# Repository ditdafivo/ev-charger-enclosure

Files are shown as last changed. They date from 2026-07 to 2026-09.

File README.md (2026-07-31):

# EV charger enclosure

This repository generates an OpenSCAD model, bill of materials, cut list, and
shopping list for a configurable outdoor EV charger enclosure.

## Generate and publish

Install [uv](https://docs.astral.sh/uv/), then run:

```bash
uv run build.py
```

Outputs are written beneath `output/`. By default, the generated model is also
committed to the repository's generated `pages-source` branch and pushed to
GitHub. That push starts the Pages workflow, which rebuilds the browser-based
OpenSCAD Playground at:

<https://ditdafivo.github.io/ev-charger-enclosure/>

Publishing uses the authenticated `origin` Git remote. A network or GitHub
failure produces a warning without discarding local output. To generate files
without publishing, use:

```bash
uv run build.py --no-deploy
```

Automatic publishing is also skipped unless the working tree is clean and the
current commit exactly matches its freshly fetched upstream branch. This keeps
generated Pages deployments from getting ahead of the source code on GitHub.

The `--width`, `--depth`, and `--height` options customize the enclosure. Run
`uv run build.py --help` for their descriptions.

## First deployment

GitHub Pages must use GitHub Actions as its publishing source. If the first
deployment reports that Pages is not enabled, open **Settings → Pages**, choose
**GitHub Actions** under **Build and deployment → Source**, and rerun
`uv run build.py`.

The build also writes `output/gusset_plate_6x6.dxf`, an inch-unit laser-cut
file for the custom G90 top-bracing gusset. To regenerate the committed
fabrication copy directly, run:

```bash
uv run python tools/generate_gusset_dxf.py
```

Printable ASA tambour tracks, removable keyed joint collars, clearance coupons,
end stops, loading sections, and the pull handle are generated as STEP and STL
files beneath `output/tambour/`. Generate the complete set, or one named part,
with:

```bash
uv run python tools/generate_tambour_parts.py
uv run python tools/generate_tambour_parts.py --part clearance_coupon_0.5mm
```

The geometry uses millimetres and targets a 350 mm printer bed with a 0.6 mm
nozzle. Print and condition the clearance coupons before committing to the
production tracks; the default 0.5 mm running clearance is only a starting
point. The generated CSV and JSON manifests give print quantities and finished
bounding dimensions. Print two common dovetail-collar shoes for every track
joint, plus two pull handles. `joint_fit_preview.step` shows two test tracks,
the expansion gap, and both collars in their installed positions.

The workflow builds directly from the pinned public OpenSCAD Playground
submodule. No NAS, container runtime, deployment key, personal access token, or
committed WASM output is required.

## Licensing

The original enclosure code, documentation, and owner-created 3D assets are
available under the [MIT license](LICENSE). The customized and compiled
OpenSCAD Playground remains GPL-covered. See
[THIRD_PARTY_NOTICES.md](THIRD_PARTY_NOTICES.md) for the exact boundary and
third-party licensing information.

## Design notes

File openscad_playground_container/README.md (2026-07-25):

# OpenSCAD Playground Pages build

This directory contains the pinned OpenSCAD Playground source, the GPL-covered
customization patches, and the static GitHub Pages build helper.

Initialize the submodule and generate a local-only enclosure model:

```bash
git submodule update --init
uv run build.py --no-deploy
```

Prepare the model path expected by the Playground, then build with:

```bash
sed 's#../assets/components/ev_charger_plug/ev_charger_plug\.stl#ev_charger_plug.stl#' \
  output/model.scad > /tmp/model.scad
./openscad_playground_container/scripts/build-pages.sh \
  /tmp/model.scad openscad_playground_container/dist local
```

Normal publication does not require this manual step. `uv run build.py` pushes
the prepared model to `pages-source`, and `.github/workflows/deploy-pages.yml`
runs the helper and publishes its output.

The build copies the upstream license bundle and an exact corresponding-source
revision notice into the deployed site. See the repository's
`THIRD_PARTY_NOTICES.md` for licensing details.

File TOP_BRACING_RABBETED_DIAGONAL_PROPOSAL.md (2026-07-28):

# Custom-gusset top-diagonal detail

## Status and purpose

This document records the implemented replacement for the catalog-plate joint
in the previous top-bracing commit. The structural screening load and member
checks remain in [`TOP_BRACING.md`](TOP_BRACING.md).

## Implemented framing

- `brace_fl_bl` and `brace_fr_br` remain top-flush 4x4 side members from
  `z = 43.50` through `z = 47.00`.
- The front and rear perimeter members remain top-flush 2x4s.
- `post_bl` and `post_fr` are 3/4 inch shorter than the other posts and stop at
  `z = 46.25`. They are not rabbeted.
- The diagonal is ripped from nominal 1x6 stock to a calculated 4.907-inch
  default finished width and occupies `z = 46.25` through `z = 47.00`. Its
  35.133-inch rectangular blank follows the post-center line at 37.44 degrees.
  Both ends are jigsawed to the modeled six-sided footprint, fully covering
  both post tops without crossing their exterior XY faces.
- The diagonal's footprint is routed 3/4 inch into the four intersected side
  braces. There are no routed post seats.

The angled board fills both shortened posts' complete top footprints. Its
minimum width is recalculated from post spacing as the square-post projection
normal to the center-to-center brace axis.

## Custom gusset

Each involved corner receives one flat 6-by-6-inch laser-cut plate. The plate
is positioned against the corner's two exterior post faces and extends inward,
covering the post, both adjoining side braces, and the diagonal.

Fabrication specification:

| Property | Value |
|---|---:|
| Material | G90 galvanized steel |
| Thickness | 0.074 inch |
| Overall outline | 6.000 by 6.000 inches |
| Hole pattern | 4 by 4 square grid |
| Hole center coordinates on each axis | 0.750, 2.250, 3.750, 5.250 inches |
| Hole diameter | 13/64 inch (0.203125 inch) |
| Quantity | 2 identical plates |

The DXF uses inches and contains one closed outline plus sixteen circle
entities on the `CUT` layer. Generate it with:

```text
uv run python tools/generate_gusset_dxf.py
```

The committed result is `fabrication/gusset_plate_6x6.dxf`; a normal model
build also writes `output/gusset_plate_6x6.dxf`.

## Fasteners

Model sixteen #9 pan-head screws per plate, thirty-two total. The OpenSCAD
geometry represents only each pan head above the plate. Neither the model,
DXF, BOM, nor instructions model or specify screw length.

The uniform grid is positioned so its centers lie over the post, side braces,
or diagonal in the default geometry. Final screw type, length, coating,
penetration, edge distances, and group capacity require an approved structural
connection design. The custom plate must not be assigned a catalog connector's
published capacity.

## Roof interface

The plate plus modeled screw head projects 0.184 inch above `z = 47.00`.
The 1/4-inch ripped pressure-treated shims cover the exposed perimeter framing
and both non-gusseted corner posts, stop at the gusset envelopes, and retain the
roof support plane at `z = 47.25`. The decking spans the short interruptions and
finishes at `z = 48.25`.

## Acceptance checks

Before removing temporary bracing, verify:

- the shortened posts terminate at the diagonal underside and have no routed
  top seats;
- no diagonal geometry extends past the exterior XY faces of either involved
  post;
- all four side-brace rabbets are flat, full depth, and free of splits;
- both gussets sit flat across the modeled intersection;
- every screw location has solid wood below it;
- the selected fasteners and custom plate have an approved capacity for the
  798-pound ASD diagonal demand documented in `TOP_BRACING.md`;
- roof shims stop clear of the plates and heads while preserving drainage; and
- tambour, wiring, siding, and service clearances remain unobstructed.

## Decision log

| Date | Decision | Result |
|---|---|---|
| 2026-07-27 | Fully cover both shortened post tops with the diagonal. | The brace now follows the post-center line, is ripped from 1x6 stock to the calculated minimum width, and has jigsaw-profiled ends. |
| 2026-07-27 | Remove the former diagonal extensions beyond the posts. | Superseded by the full-post, jigsaw-profiled detail above. |
| 2026-07-27 | Shorten the involved posts instead of rabbeting them. | `post_bl` and `post_fr` stop 3/4 inch below the frame top. |
| 2026-07-27 | Retain rabbets only at intersected side braces. | Four routed seats remain. |
| 2026-07-27 | Replace HTP37Z hardware with custom gussets. | Two identical 6-by-6-by-0.074-inch G90 plates with sixteen-hole grids are modeled. |
| 2026-07-27 | Leave #9 pan-head screw length open. | Heads and quantities are modeled; length is absent from all specifications. |

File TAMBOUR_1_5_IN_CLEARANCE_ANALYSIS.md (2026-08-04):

# Tambour 1.5-Inch Slat Clearance Analysis

## Conclusion

The modeled tambour clears the fixed framing, siding, street-light backers,
revised charger-feed conduit, and removable plywood ceiling throughout a dense
sweep of the complete track. The check uses the actual asymmetric envelope:
7/8 inch outward from the track centerline for the slat and handle, and
5/16 inch inward for the slat, webbing, reinforcement, and fastener heads. The
1 3/16-inch actual stack remains inside the 1 1/2-inch maximum envelope.

The production channel clearance, printed-track fasteners, slat-end clearance,
joint clips, loading section, and exact inward fastener stack remain
prototype-controlled. The rendered
charger cord is illustrative
and is not treated as a hard clearance envelope; the plywood ceiling guards the
overhead curtain from hands and the cord.

## Resolved geometry

| Region or object | Result |
| --- | ---: |
| Perimeter top braces | 0.25-inch clearance |
| Shallow top diagonal | Approximately 1-inch clearance |
| Lowered `rail_ft` and front bend | At least 0.25-inch modeled clearance |
| Front street-light backers | 0.325-inch planar clearance |
| Charger-riser feed | Clears below or behind the front curtain |
| Plywood ceiling | 0.25 inch below the horizontal curtain envelope |
| Rear trim and lateral slat ends | Prototype-controlled guide detail |

### Front guide and street-light backers

The slat and guide share the groove centerline at `y = 5.0`. The minimum safe
datum from the fixed street-light backers is `y = 4.925`; it is rounded
rearward to the next 1/8 inch for construction. The outward handle envelope
therefore reaches forward to `y = 4.125`, while the backers end at `y = 3.80`:

```text
4.125 - 3.80 = 0.325 inch
```

The left and right vertical support rails move with the guide and occupy
`y = 4.25` to `y = 5.75`. The 3/4-inch plywood bend backers continue rearward
to `y = 7.25` and occupy `z = 42.375` to `z = 43.5`, above `rail_lt` and
`rail_rt`, so the complete printed flange remains supported without overlapping
the receiver rails.

### Structural front header

`rail_ft` remains a 2x4 but moved down to `z = 40.875` through `z = 42.375`.
The front center rail bears against its underside. The header spans directly
between `rail_lt` and `rail_rt`, which provide its full-depth end attachment
faces; the former vertical header-support blocks are not used.

The regression follows the resolved piecewise track and checks both the full
7/8-inch outward handle envelope and the full 5/16-inch inward slat/hardware
envelope over the header's Y interval and through both bends. Separate dense
samples of the complete printed-track cross section prove backing support and
absence of lumber penetration through the 2 5/8-inch-radius front bend.

This is a geometry result, not a structural rating. The header, blocks, center
rail, fasteners, and connections must be selected for the charger dead load
and repeated lateral and torsional loading from wrapping the cord and handling
the plug.

### Charger-feed conduit

The charger-riser arrangement aligns the 1 1/4-inch ground riser and T body
with the charger's conduit-port X coordinate. Its complete horizontal branch
runs 1/4 inch above `rail_fb` to the rear of the junction box, while the
reduced 1-inch feed rises directly from the T body to the charger. Both feeds
remain below or behind the front curtain envelope.

The #6 charger group bypasses the junction box through the T body. The box's
remaining #12 groups require 18 cubic inches against its modeled 49-cubic-inch
marking, leaving 31 cubic inches.

### Removable plywood ceiling

The modeled exterior-plywood panel occupies:

```text
x = 3.5 to 24.0 inches
y = 9.6875 to 17.625 inches
z = 43.25 to 43.50 inches
```

Its top is 9/16 inch below the inward horizontal curtain envelope at
`44.375 - 0.3125 = 44.0625` inches.
Its rear edge is inset 3/4 inch from the rear bend tangency; its front edge
aligns with the positive-Y face of `rail_ft`. Mount it on independent removable
retainers so track inspection, cleaning, and curtain removal remain possible.

## Rear trim and slat ends

“Rear trim and slat ends” refers to the left and right ends of each slat where
the curtain passes through the rear opening, not the trailing end of the
curtain. The simplified model draws each slat to both track centerlines, while
the rear opening angles reach those same lateral boundaries. A production
slat instead terminates with running clearance inside the printed side-opening
channel, with the trim concealing the interface.

Because the accepted printed clearance, end engagement, and installed track
spacing remain prototype-controlled, this interface must be approved on the
full-width test frame.

## Acceptance requirements

1. Build the guide paths from one full-size template using the modeled
   front `y = 5.0`, top `z = 44.375`, rear `y = 21.0`, and 2 5/8-inch-radius
   track datums.
2. Verify the header load path and connections for the charger and holster's
   dead and dynamic loads.
3. Prototype the printed channel, clearance coupons, slat ends, pulls,
   fasteners, loading section,
   and removable ceiling retainers.
4. Cycle the curtain through full travel before and after installing the
   ceiling, conduit, fixed cables, siding, and trim.
5. Record the production dimensions and revise the model if the approved
   prototype differs from the modeled maximum envelope.

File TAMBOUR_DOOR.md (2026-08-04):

# Custom Tambour Door Prototype and Build Guide

This guide defines how to develop, prove, fabricate, install, and maintain the
custom tambour door shown in the enclosure model. It supplements
[`BUILD_STEPS.md`](BUILD_STEPS.md); it is not a claim that the current modeled
slat and track dimensions are a proven shop drawing.

The door is intended to be an attractive visual barrier that is easy to open,
close, clean, and service. It is not a security barrier or a weather seal. Do
not add locks, gaskets, springs, or counterweights without revisiting the path,
clearances, operating force, and maintenance requirements.

## Modeled starting geometry

Use these values to lay out the first full-size prototype. Values marked
"prototype-controlled" may change before production and must be recorded in
the build record at the end of this guide.

| Feature | Modeled value | Status |
| --- | ---: | --- |
| Distance between left and right track centerlines | 20 1/2 in | Verify against the built frame |
| Rear lower track endpoint | `y = 21`, `z = 3` in | Fixed enclosure interface |
| Front lower track endpoint | `y = 5`, `z = 16` in | Fixed enclosure interface |
| Top track centerline | `z = 44 3/8` in | Fixed enclosure interface |
| Rear straight run | 38 3/4 in | Derived from installed datums |
| Top straight run | 10 3/4 in | Derived from installed datums |
| Front straight run | 25 3/4 in | Derived from installed datums |
| Track offset into slat | 0 in; path is groove center | Fixed enclosure interface |
| Bend centerline radius | 2 5/8 in | Prototype-controlled |
| Curtain length | 44 in | Prototype-controlled |
| Slat pitch | 25/32 in | Prototype-controlled |
| Slat travel-direction height | 3/4 in | Prototype-controlled |
| Wooden slat face depth | 1/2 in | Prototype-controlled |
| Complete swept depth envelope | 1 1/2 in | Fixed clearance limit |
| Rendered track diameter | 1/2 in | Visualization only |
| Removable ceiling panel | 20 1/2 by 7 15/16 by 1/4 in | Fixed enclosure interface |

The model places 56 slats on the 44-inch curtain. The 1/32-inch difference
between the 3/4-inch slat height and 25/32-inch attachment pitch is a setup
allowance, not a promise of a permanently visible gap. The lower stop supports
the closed curtain, adjacent slats may settle together, and the webbing can bow
locally. The detailed model draws the channel and its mounting flange; printable
track solids and test coupons are generated separately with build123d.

The track datum and wooden slat center now share the running-groove centerline.
In the X direction, that datum is also the lumber mounting face: the printed
flange and channel project from it into the door opening rather than into the
supporting lumber.
The actual 1/2-inch slat is rendered at `z = 44.375` on the top run. Clearance
checks use an asymmetric swept envelope: 7/8 inch outward from the groove
centerline for the slat plus 5/8-inch handle, and 5/16 inch inward for the slat
plus no more than 1/16 inch of webbing, reinforcement, and fastener-head
projection. The resulting 1 3/16-inch stack remains within the fixed
1 1/2-inch maximum. The outward envelope retains 1/4 inch below the braces:
`44.375 + 0.875 = 45.25` inches. No handle, screw head, webbing, reinforcement,
or track fixing may extend beyond its applicable side of this approved
envelope.

## Provisional construction

Use the following construction family for the prototypes:

- Dry, straight pressure-treated stock surfaced to 1/2 inch for the slats.
  Reject twisted, cupped, checked, severely incised, or irregular stock. Use a
  planer, purchased surfaced stock, or outsourced milling rather than resawing
  a wide board on edge with only a table saw. Field-treat and seal cut faces.
- At least three exterior-rated polyester webbing strips on the concealed face,
  mechanically fastened to every slat without pre-tension. Keep fasteners clear
  of the captured ends and handle screws.
- ASA track segments with integral mounting flanges as the replaceable running
  surface. Print the clearance coupons before production parts; a separate
  UHMW liner is not part of the initial design.
- Corrosion-resistant fasteners outside the running surface. Fix each track
  segment at its center and use slotted outer holes so it can expand without
  buckling.
- Replaceable end stops and paired removable loading sections at the lower rear
  ends of the tracks. The curtain must remain removable after siding, trim, and
  electrical equipment are installed.

Make both guide paths from the same full-size master template. Mark every
track segment, keyed collar, spacer, loading section, and end stop
left/right and front/rear so that matched pieces return to their proven
positions. Keep the running surfaces
smooth and free of exposed screw heads, abrupt joints, plastic strings,
and pockets that retain grit or water. Provide cleanout and drainage at both
low endpoints.

Commercial tambour instructions emphasize consistent, aligned tracks and
keeping debris out of the slats. Printed ASA also requires expansion gaps and
independently aligned segments rather than a long rigid run. See the
[Tambour Doors installation guidance](https://tambourdoors.eu/installation-guides/),
[Tambortech installation instructions](https://www.tambortech.com.au/fileadmin/user_upload/downloads/2013_Tambour_Door_Install_Sheet.pdf),
and the printable-part instructions below.

## Printable ASA parts

Run `uv run python tools/generate_tambour_parts.py` to write the complete STEP,
STL, and quantity manifests beneath `output/tambour/`. Use `--part NAME` while
developing a coupon or replacement. Do not scale meshes in the slicer; change
the Python configuration and regenerate them so track and collar clearances stay
coordinated.

The baseline assumes a 0.6 mm nozzle, 0.3 mm or finer layers, at least four
perimeters, and an enclosed ASA-capable printer. Put each track's mounting
flange on the build plate; both handed exports are already oriented this way.
Use enough top and bottom layers and infill to make screw counterbores and the
handle ribs solid in practice. Follow the filament manufacturer's temperature,
drying, ventilation, and fume-control instructions. Do not anneal production
parts unless identically treated coupons demonstrate that dimensional change
does not consume the accepted running clearance.

The fixed straight runs are divided into equal segments below 300 mm. The rear
loading section replaces the lowest 100 mm of fixed track; it is not added to
the path length. Keep the configured 0.6 mm expansion seam between track ends.
At every joint, slide one external dovetail-collar shoe down each channel wall,
then retain each shoe with a recessed M3 stainless screw in its heat-set insert.
The shoes index both channel walls while leaving the running channel empty and
allowing limited longitudinal thermal movement. Remove both screws and lift the
shoes outward before lifting an individual segment. The collars align the
tracks but do not replace the segment mounting screws. Print the two joint-test
tracks first and inspect `joint_fit_preview.step` for the installed orientation.
Keep the open drain notch in each lower stop unobstructed.

## Pull slats

Make two special pull slats as part of the curtain:

1. The lowest slat is the normal opening pull. When the door is open, this slat
   travels onto the upper run and also serves as the closing pull.
2. Place a second pull approximately 18 inches above the lower curtain edge.
   At the modeled 25/32-inch pitch this is nominally the twenty-fourth slat when
   the lowest slat is counted as the first. Set its final position from the
   actual production pitch, not merely the nominal slat count.

Rear elevation, door closed (not to scale):

```text
                  top track centerline z = 44.375
       left track  |==========================|  right track
                   |                          |
                   |  upper printed lift ledge|  about 18 in above lower edge
                   |  <-------------------->  |
                   |                          |
                   |  lowest printed lift ledge| normal opening pull
                   |  <-------------------->  |
                   +--------------------------+  lower edge about z = 3
```

Side path and handle orientation (not to scale):

```text
 rear opening                                      enclosure front
 y = 21                                                     y = 5
    |        top brace underside z = 45.5                    |
    |        ----------------------------------               |
    |        1/4-in minimum clearance                         |
    |      / printed ledge rotates onto top run \              |
    |     /======================================\ z = 44.375 |
    |     |                                      |            |
    |     |                                      |            |
 z = 3 --+                                      +-- z = 16

 The modeled 5/8-in proud handle is included in the 1/4-in clearance.
 The printed ledge must remain inside the approved 1 1/2-in envelope.
```

The model includes a removable 1/4-inch exterior-plywood ceiling from
`y = 9.6875` to `y = 17.625` and `z = 43.25` to `z = 43.5`. Its front edge
aligns with the positive-Y face of `rail_ft`, avoiding an unnecessary forward
overhang. It shields the overhead curtain from hands and the charger cord while
retaining 1/4 inch below the maximum curtain envelope. Support it on independent
removable retainers; do not fasten through a printed track or obstruct track
inspection.

Attach one centered printed ASA lift ledge to each pull slat. The nominal ledge
is 300 mm wide, no more than 5/8 inch proud of the wood face, and secured from
the outward side with multiple short corrosion-resistant wood screws in
recessed counterbores. The screw tips must not penetrate the concealed face;
the modeled handle attachment therefore has no screw head on the inward plane.
It must remain entirely on one slat and permit a centered one-hand grip or a
wide two-hand grip.

The approved pull profile must meet all of these conditions:

- Nothing projects beyond the approved asymmetric swept envelope in any
  direction.
- Webbing, reinforcement, and all heads on the inward face project no more than
  1/16 inch beyond that face. A proposed through-fastener with its head or nut
  on the inward face is a design change and must pass the bend coupon before
  use; it is not the modeled handle fastening method.
- The printed grip and its edges are smooth, rounded, drainable, and free of
  layer separation or sharp support scars.
- Screw pilot holes retain enough wood to keep the 1/2-inch pull slat straight
  under the proof load without penetrating the concealed face.
- The webbing connection at each pull slat is reinforced within the approved
  curtain envelope. Force on the upper pull must not depend only on one screw
  or one webbing strip.
- The grip cannot trap a finger against the next slat or either track while the
  curtain enters a bend.

A bail, folding handle, knob, proud screw, or webbing loop is not acceptable:
every slat-mounted feature travels through both bends and under the top
bracing. Prototype the printed ledge and complete fastener stack before making
the full curtain.

## Prototype sequence

Do not fabricate the final curtain and tracks in one pass.

### 1. Material and pull coupons

Mill several short 1/2- and 3/8-inch-deep slats at the modeled 3/4-inch height.
Ease the moving edges, fasten actual webbing, and mount one printed handle.
Apply the proposed field treatment and finish. Check articulation, screw
holding, drainage, grip comfort, and whether the pull remains straight under
the 15-pound proof load described below. Keep 1/2 inch as the production depth
unless the thinner coupon passes every wind and durability test.

### 2. Full-size path template

Lay out the complete side path at full scale, including both 2 5/8-inch-radius
bends and both lower endpoints. Use a fair curve with tangent transitions; do
not approximate the bend with a sharp miter. Make a rigid master template and
use it for both mirrored track assemblies.

### 3. Short-curtain track test

Print the 0.3, 0.5, and 0.7 mm-per-face clearance coupons, then one complete
bend and its tangent stubs. Run a short webbing-linked group of ordinary and
pull slats through it. Select the tightest conditioned coupon that runs freely,
then adjust only slat edge easing and setup gap until the sample moves without
pinching, chatter, or visible skew. Generate both track hands with that
accepted clearance.

### 4. Full-width test frame

Build a rigid test frame at the measured production track spacing. Use fixed
spacers or an alignment gauge at the rear vertical, both bends, top run, and
front vertical. Install the removable loading sections and end stops exactly
as they will be installed in the enclosure.

### 5. Full-curtain test

Fabricate the 44-inch curtain using the two pull slats. Load it through the
service sections, fit the stops, and perform the acceptance tests below. Test
the bottom pull from the center and with hands spread toward both tracks. Test
the upper pull the same way.

If the completed door exceeds the operating-force limit, first reduce the slat
mass and repeat the short-curtain and full-curtain tests. Adjust the model after
the production profile is approved. Do not mask an excessively heavy curtain
with extra track friction, and do not add a spring or counterweight as part of
this design.

## Enclosure installation

Install the approved tracks only after both vertical supports, both 3/4-inch
plywood bend backers, and the top side 4x4s are fixed. Install and verify the
tracks before loading the door, and complete both operations before electrical
backing, conduit, siding, or trim restricts access.

1. Measure the actual frame and compare it with the prototype test frame.
2. Use the prototype alignment gauges to position both guide paths. Shim the
   mounting flanges as needed; do not pull a crooked segment straight with
   screws.
3. Fix each ASA segment at its center, use its slotted outer holes, preserve
   the accepted joint gaps, and keep every fixing outside the running surface.
4. Load the completed curtain and cycle it fully. Confirm the printed pulls
   clear both bends and all installed framing, including at least 1/4 inch of
   clearance below the already installed top braces throughout their travel.
5. Mark all matched parts, then remove the curtain, loading sections, and end
   stops. Cover the fixed tracks against dust, cuttings, paint, and finish
   during the remaining work.
6. After siding and trim, uncover and clean the tracks. Confirm that no
   fastener or trim movement changed their spacing.
7. Reinstall the curtain, loading sections, and stops, then repeat the full
   acceptance test, including clearance from the already completed conduit
   and fixed cable routes. Install the removable ceiling and repeat the test.

The rendered charger cord is illustrative rather than an accurate operating
envelope. Do not use its modeled path as a hard tambour-clearance datum; the
ceiling panel provides the physical guard beneath the overhead curtain.

The OpenSCAD build-step view shows the completed tambour assembly beginning at
its trial-fit step. It does not attempt to depict the curtain's temporary
removal during the intervening construction work.

## Snow operation

The modeled lower curtain edge is only about 3 inches above nominal grade, so
drifting, shoveled, or plowed snow can cover the lowest pull even though the
door is not intended as a weather barrier. The upper pull provides a reachable
grip; it is not a pry point for breaking a frozen door loose.

After snowfall:

1. Clear snow away from the face of the curtain, both track edges, and the rear
   lower track endpoints.
2. Free any ice bond without levering against a slat or printed track.
3. Use a wide or two-handed grip on the upper printed pull and apply smooth,
   even force until the bottom pull is exposed.
4. Transfer to the bottom pull for normal operation.
5. Stop if the door racks, binds, or requires more than its normal operating
   effort. Clear the obstruction rather than forcing the curtain.

## Acceptance tests

Approve the production design only after it passes all of the following on the
full-width test frame and again in the enclosure:

- Complete at least 100 full open-close cycles without binding, derailment,
  webbing separation, handle damage, or visible track wear.
- Measure no more than 5 pounds peak normal operating force anywhere in the
  travel, using the center and the left and right thirds of both pulls.
- Apply a 15-pound static load to each printed pull for one minute without
  cracking, permanent deformation, screw withdrawal, or webbing separation.
- Apply approximately 4.7 pounds uniformly to a conditioned full-span slat and
  screen the complete closed door and supports for the project's approximately
  260-pound distributed ultimate wind load.
- Confirm that center operation does not rack the curtain and that a deliberate
  modest left/right imbalance does not cause derailment.
- Confirm that the curtain cannot run away, leave either endpoint, or create an
  accessible pinch point during ordinary operation.
- Sweep the complete handle and reinforcement envelope through both bends and
  the top run without contact.
- Remove and reinstall the curtain without removing siding, trim, electrical
  equipment, or a permanent track section.
- Repeat the functional and clearance checks after track installation, after
  siding and trim, and after the final cable routes are installed.

## Production build record

Complete this record before final fabrication and use the approved values to
update the model and generated material outputs in a later change.

| Item | Approved value or product |
| --- | --- |
| Actual installed track spacing | |
| Bend radius | |
| Slat species and moisture condition | |
| Slat pitch, travel width, depth, and end clearance | |
| Ordinary edge profile | |
| Printed pull revision, projection, and screw pattern | |
| Upper pull position from lower curtain edge | |
| Webbing product, strip count, and screw pattern | |
| Field treatment and surface preparation | |
| Finish and maintenance interval | |
| ASA product, clearance coupon, and expansion allowance | |
| Fasteners and slot dimensions | |
| Loading-section and end-stop details | |
| Measured peak operating force | |
| Prototype cycle count and date | |

Until this record is complete, the tambour materials are provisional and are
not included in the generated BOM or shopping list. After approval, follow up
by splitting guide tracks, ordinary slats, and pull slats into distinct modeled
objects and adding their approved materials to the generated BOM and shopping
list.

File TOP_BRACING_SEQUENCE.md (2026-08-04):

# Top-bracing build-sequence evaluation

## Question

Record why the accepted rabbeted top bracing is installed immediately after
the posts rather than after the intermediate framing.

## Conclusion

Install the accepted rabbeted top bracing directly after the posts using the
detail in [`TOP_BRACING.md`](TOP_BRACING.md). Keep temporary external bracing
until the routed seats, custom gusset plates, complete #9 screw grids, and frame
have been inspected.

## Consolidated geometry

The left and right top perimeter members are 4x4s spanning `z = 43.50` to
`47.00`. Their inside faces and undersides replace the former top track rails,
while `rail_lt` and `rail_rt` remain below them as the side receivers for the
lowered front header. The removable ceiling remains at `z = 43.25` to `43.50`,
directly against the 4x4 undersides, while the curtain and guides remain inside
the clear opening.

The full-section diagonal remains at `z = 46.25` to `47.00`. The two involved
posts stop at its underside, and only the four intersected side braces are
routed. Custom 0.074-inch gusset plates and modeled screw heads project 0.184
inch above the frame. The 1/4-inch shims cover the exposed perimeter framing
and both non-gusseted corner posts, stop at the gusset envelopes, and establish
the roof support plane at `z = 47.25`.

## Reasons for moving the bracing after Step 2

### No modeled dependency on intermediate framing

All four perimeter members and the single diagonal connect only to the four
posts. They do not depend geometrically on the lower rails, upper rails,
vertical rails, tambour supports, door, or street-light backing introduced in
Steps 4 through 12.

The reorder is therefore feasible from the model's dependency standpoint.

### Earlier control of frame squareness

Installing the top perimeter and diagonal while the posts are being aligned
would establish the final top rectangle earlier. This reduces the period in
which plan squareness depends entirely on temporary external bracing and makes
it less likely that later installation of the permanent diagonal will disturb
already positioned framing or guide tracks.

The posts should be checked for plumb, spacing, and equal plan diagonals before
the permanent members are fastened. Those measurements should be repeated
after fastening so the bracing does not lock an error into the frame.

### Better tambour alignment and acceptance testing

The former sequence trial-fitted the tambour before installing the permanent
top bracing and checked the curtain against the bracing's modeled envelope.
With the bracing installed earlier, the production tracks and curtain are
aligned and tested against the actual completed framing.

This is preferable because the installed braces, connections, and permitted
construction tolerances—not their idealized model envelopes—control the real
clearance.

### Improved access from the shallow diagonal

The rabbeted, ripped nominal 1x6 diagonal has an underside at `z = 46.25` inches.
The maximum approved tambour envelope reaches `z = 45.25` inches on its top
run, leaving approximately:

```text
46.25 - 45.25 = 1.00 inch
```

This 1-inch minimum clearance beneath the diagonal is substantially greater
than under the former 2x4 diagonals. It makes early installation less likely
to obstruct later tambour work.

The side 4x4s occupy the former side-support footprint rather than crossing the
clear curtain opening. Verify the production tracks, curtain, printed pulls,
fasteners, and ceiling retainers against their actual inside faces.

## Temporary-bracing limitation

Early installation of the top-plane bracing is not by itself a reason to
remove all temporary external bracing. It controls distortion of the top
rectangle, but it does not necessarily prevent all four posts from leaning or
swaying together in a vertical plane.

The build guide should continue to require temporary support until the
installed rails and other permanent framing provide adequate stability in
every direction and the permanent top-brace connections have been approved.

## Structural-connection installation

Route and dry-fit the four side-brace seats before installing hardware. Place
each 6-by-6 gusset against the two exterior faces of its post and fill its
sixteen-hole grid with #9 pan-head screws. The model intentionally leaves screw
length unspecified. Inspect plate seating, wood splitting, screw clearance,
and the post/perimeter load path before removing temporary support.

## Revised sequence

The revised sequence is:

1. Complete the underground conduit risers and restore grade.
2. Install the four posts with temporary external bracing.
3. Install the complete top perimeter and diagonal bracing while checking post
   plumb, spacing, plan diagonals, and the approved connection details.
4. Complete the lower and upper framing through Step 9.
5. Install the plywood bend backers in Step 10, the fixed tracks in Step 11,
   and the tambour door in Step 12.
6. Trial-fit the removable guard in Step 13, then complete the electrical,
   siding, trim, and finish work through Step 27.

The complete sequence contains 27 build steps, so `build_step = 28` represents
the completed model.

## Implemented project updates

The model, tambour prototype guide, build sequence, and build-step assertions
use the resolved geometry and early-bracing sequence. The tambour trial fit is
performed against the installed bracing, and temporary external bracing remains
required until the permanent frame and connections are approved and stable.

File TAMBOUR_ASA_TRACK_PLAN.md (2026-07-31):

# Lightweight ASA Tambour Track and Wooden Curtain

## Summary

Design a modular ASA track and lightweight wooden tambour using 1/2-inch-thick,
3/4-inch-high pressure-treated slats. The slats settle against one another when
closed; mechanical webbing links them, limits separation, and pulls them during
closing but does not hold them apart under gravity.

Retain the existing 1 1/2-inch swept clearance envelope and 2 5/8-inch bend
radius. Prototype 3/8-inch slats as an optional later weight reduction, but use
1/2 inch as the production baseline unless the thinner version passes the same
wind, screw-holding, and durability tests.

## CAD and model changes

- Add build123d as a pinned dependency and generate exact STEP and STL
  fabrication files beneath `output/tambour/`.
- Generate mirrored track sets with straight sections no longer than 300 mm,
  exact tangent bends, side-opening U-channels, integral mounting flanges,
  expansion slots, drainage, removable loading sections and stops, and paired
  external keyed collars that align both channel walls while permitting
  individual segment removal.
- Size printable features for a 0.6 mm nozzle, including nominal 2.4 mm minimum
  walls and reinforced channel/flange transitions.
- Give every track end exterior dovetail pads and retain each paired collar
  with a recessed M3 stainless screw and heat-set insert. Preserve a nominal
  0.6 mm end gap and keep all joint features outside the running channel.
- Provide 0.3, 0.5, and 0.7 mm-per-surface running-clearance coupons. Generate
  production tracks using the tightest clearance that passes the conditioned
  coupon and bend tests.
- Model the actual 1/2-inch slat depth, 3/4-inch travel height, initial
  1/32-inch straight-run gap, 25/32-inch attachment pitch, 44-inch curtain,
  retained 3/8-inch guide-datum offset, and an independent 1 1/2-inch swept
  assembly envelope.
- Generate a replaceable, centered, approximately 300 mm-wide ASA lift ledge
  on each of two pull slats. Limit projection to 5/8 inch and keep every handle
  entirely on one slat and inside the swept envelope.

## Curtain fabrication

- Obtain pressure-treated stock that can be safely surfaced to 1/2 inch using
  a planer, purchased surfaced stock, or outsourced milling. Do not resaw a
  wide board on edge using only the table saw.
- Dry and acclimate stock before final surfacing. Reject warped, checked,
  twisted, or severely incised pieces and record moisture condition.
- Rip the surfaced stock into 3/4-inch-high slats using a repeatable table-saw
  jig. Crosscut from one stop, ease moving edges, and field-treat and seal every
  cut or surfaced face.
- Lay slats face-down against 1/32-inch setup spacers and attach at least three
  exterior-rated polyester webbing strips without stretching them. Fasten the
  webbing mechanically to every slat, outside the track and handle regions.
- Let the lower stop carry the closed curtain vertically. Slat contact carries
  compression; the webbing is not a tensioned spacing belt in this state.

## Structural and wind validation

- Use the existing 44.1 psf ultimate wind-pressure screen. Check each
  20 1/2-by-3/4-inch slat for approximately 4.7 pounds of distributed load and
  the complete door and supports for approximately 260 pounds distributed over
  the door area.
- Test conditioned full-span 1/2- and 3/8-inch coupons with at least 5 pounds
  distributed across one slat. Inspect bending, permanent set, splitting,
  track-edge crushing, and fastener movement.
- Retain 1/2 inch as the production thickness. Adopt 3/8 inch only after it
  passes all structural and operating tests with acceptable margin.
- Treat calculations as screening and prototype requirements rather than a
  stamped structural rating.

## Prototype sequence

1. Print clearance, keyed-collar joint, screw-slot, and handle coupons.
2. Mill short 1/2- and 3/8-inch samples and test finish, swelling, screw holding,
   and edge treatments.
3. Build one complete bend with short straight sections.
4. Assemble a short curtain at 25/32-inch pitch with 1/32-inch setup gaps and
   the actual webbing.
5. Verify settling, bend articulation, edge clearance, and visual closure.
6. Adjust only edge treatment, setup gap, and accepted channel clearance from
   these tests; retain 3/4-inch slat height and 1/2-inch production thickness.
7. Build a rigid full-width test frame using installation gauges.
8. Assemble and test the complete curtain and both pull slats.

## Acceptance criteria

- Complete at least 100 full cycles without binding, derailment, webbing
  separation, joint catching, handle damage, or significant track wear.
- Require no more than 5 pounds peak operating force for centered and
  deliberately off-center pulls.
- Apply a 15-pound handle load for one minute without cracking, screw
  withdrawal, splitting, or permanent deformation.
- Confirm gravity-assisted closure without manually stacking individual slats,
  visually minimal gaps, and no binding after moisture conditioning.
- Pass the distributed slat and complete-door wind tests.
- Keep all actual components inside the 1 1/2-inch swept envelope.
- Permit track-segment, loading-section, stop, handle, and curtain replacement
  without removing siding or permanent electrical equipment.
- Require the keyed joint coupon to cross without catching, withstand a
  10-pound transverse load, and survive 25 removal/reinstallation cycles.
- Repeat operating and clearance tests after final track installation, siding,
  trim, electrical routing, and ceiling installation.

## Assumptions

- The tambour is a visual barrier, not an airtight weather seal or security
  door.
- Shorter 3/4-inch-high slats improve articulation; additional slats restore
  the required curtain length.
- Gravity may reduce straight-run gaps because webbing can bow locally, but
  operation cannot depend on uncontrolled slack.
- Captured slat ends and tracks carry transverse wind load; webbing primarily
  maintains continuity and alignment.
- ASA is a replaceable direct-running guide material without an initial UHMW
  liner.
- Drilling, countersinking, sanding, planing, and jig-making tools may supplement
  the table saw. No router is required.

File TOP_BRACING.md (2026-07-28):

# Top-plane bracing evaluation

## Decision

Use one stress-rated nominal 1x6 diagonal across the back-left and front-right
posts. Rip it from its 5.5-inch stock width to the calculated 4.907-inch
finished width. The default rectangular blank is 35.133 inches long, runs
post-center to post-center at 37.44 degrees, retains a 25.320-inch clear span,
and occupies `z = 46.25` to `47.00`. Jigsaw the two end profiles to the modeled
six-sided footprint. The finished member fully covers both shortened post tops
without crossing their exterior XY faces.

Shorten `post_bl` and `post_fr` by the diagonal depth so their tops are at
`z = 46.25`. Route 3/4-inch seats only where the diagonal crosses the four side
braces. Connect each corner with one custom 6-by-6-by-0.074-inch G90
galvanized-steel gusset and a 4-by-4 grid of #9 pan-head screws. Fastener length
is deliberately unspecified.

The two side perimeter members are top-flush 4x4s occupying `z = 43.50` to
`47.00`; they replace the former upper and tambour side rails.

The brace is still required because none of the other modeled construction is
a defined structural diaphragm.  The four perimeter rails have unspecified
end connections, and the gapped composite roof and wall boards are neither
structurally rated sheathing nor installed with a structural fastening
schedule.  Eliminating the diagonals would therefore leave top-frame racking
resistance to unquantified joint stiffness and cladding friction.

One wood diagonal is sufficient in principle: it changes between tension and
compression when the shear direction reverses.  The former second diagonal
did not create a useful independent load path because its crossing joint and
both members' end connections were undefined.

## Site and screening load

The Boulder County GIS wind and snow layers return the following values at the
project parcel:

- ultimate design wind speed: 155 mph;
- ground snow load: 40 psf.

For a conservative screening calculation, use Exposure B at the 15-foot
minimum velocity-pressure height, `Kd = 0.85`, `Kzt = 1.0`, and an elevation
factor of 0.82.  This gives:

```text
qh = 0.00256 Kz Kzt Kd Ke V^2
   = 0.00256(0.57)(1.0)(0.85)(0.82)(155^2)
   = 24.5 psf ultimate
```

Using a deliberately high net force coefficient of 1.8 gives 44.1 psf.  On
the larger 27.5-inch by 48-inch projected face, the resulting top-level shear
screen is 404 pounds ultimate, or 242 pounds ASD after the 0.6 wind factor.
Doubling that ASD result for model and load-path uncertainty gives a 485-pound
design shear. The post-center diagonal is 30.226 inches at 37.44 degrees; the
clear span between post profiles is 25.320 inches. This produces a maximum
screened axial brace demand of:

```text
P = 485 / sin(37.44 degrees) = 798 pounds ASD
```

The 40 psf snow load governs the gravity support check of the composite roof
and perimeter members, not the in-plane axial force in this diagonal.  The
brace also does not improve whole-enclosure overturning or the lateral
capacity of the gravel footings.

### Ripped 1x6 member screen

The American Wood Council permits a stress-rated nominal 1-inch board to use
the corresponding dimension-lumber design values. For Douglas fir-larch No. 2,
use `Fc = 1,400 psi`, `Ft = 500 psi`, and `Emin = 580,000 psi`. Conservatively
apply wet-service factors of 0.80 to compression and 0.90 to `Emin`, the 1.60
wind-duration factor, no size increase, a pinned 25.320-inch effective length,
and the NDS sawn-lumber column constant of 0.8.

```text
area       = 0.75(4.907) = 3.680 square inches
Le / d     = 25.320 / 0.75 = 33.76
Fc*        = 1,400(0.80)(1.60) = 1,792 psi
FcE        = 0.822(580,000)(0.90) / 33.76^2 = 376 psi
Cp         = 0.200
Pcompression = Fc* Cp area = 1,319 pounds ASD
Ptension     = 500(1.60)(3.680) = 2,944 pounds ASD
```

The screened ripped 1x6 therefore passes member compression by approximately
65 percent and member tension by a larger margin after the wind demand has
already been doubled for uncertainty. Substituting a lower species/grade, an
incised member, a longer unsupported brace, or a connection that reduces the
net section requires a new calculation.

## Member and connection requirements

Use a stress-rated, exterior-suitable nominal 1x6 with actual dimensions of
3/4 by 5 1/2 inches and rip it slightly proud of the modeled 4.907-inch minimum
before final fitting. Specify Douglas fir-larch No. 2 or a species/grade with
equal or greater published compression, tension, and minimum-modulus values.
Reject a board with slope-of-grain defects, checks, splits, or wane in either
end-connection region.

The accepted detail and its installation must provide all of the following for
both load directions:

- at least 798 pounds ASD axial capacity in the member and at each end;
- compression stability about the 3/4-inch weak axis over the modeled length;
- tension capacity at the minimum net section;
- full seating of both plates and all thirty-two #9 pan-head screws in solid wood;
- positive transfer from the diagonal through the perimeter-frame/post joints;
- corrosion compatibility with treated lumber and the outdoor environment.

The model includes the four side-brace routed cuts, plates, screw-head
envelopes, and roof shims. It does not select screw length or establish a
published capacity for the custom connection. A qualified engineer must check
plate thickness, hole pattern, screw specification, wood edge distances, and
the complete post load path before temporary bracing is removed.

## Superseded thin-metal option

A tension-only metal solution requires an X.  A pair of coil straps would
recover almost the full 1.5 inches, but the current frame does not provide the
manufacturer-required side-grain anchorage length at all four endpoints.
Nailing a horizontal strap into the tops of the vertical posts would use end
grain, while wrapping, field-bending, or adding custom corner blocks would no
longer be the simple catalog installation being evaluated.

Metal straps are not part of the modeled design. The custom gussets are the
modeled connection.

## Roof interface

The modeled 0.074-inch plate and pan-head projection is 0.184 inch above the
47-inch frame plane. The 1/4-inch ripped PT-lumber shims cover the exposed
perimeter framing and both non-gusseted corner posts, but stop at the gusset
envelopes. They raise the composite roof support plane to `z = 47.25`; the
decking spans the short interruptions above the plates and finishes at
`z = 48.25`. Preserve drainage around both plates and increase roof-fastener
length by the shim thickness so the original substrate penetration is retained.

## Sources

- [Boulder County wind and snow load map](https://www.arcgis.com/home/item.html?id=2adc1d7dbdd244e698e265a950a0fde3)
- [Current Boulder County building-code amendments](https://bouldercounty.gov/property-and-land/land-use/building/building-code-amendments/)
- [American Wood Council guidance for stress-rated nominal boards](https://awc.org/faq/where-can-i-find-information-for-nominal-1-1-1-4-and-1-1-2-stress-rated-boards/)
- [American Wood Council 2024 NDS Supplement](https://awc.org/resources/2024-nds-supplement/)
- [Simpson Strong-Tie coil-strap installation requirements](https://www.strongtie.com/resources/product-installers-guide/cs-csmst14-installation)
- [SendCutSend G90 galvanized steel thicknesses](https://sendcutsend.com/materials/g90-steel/)

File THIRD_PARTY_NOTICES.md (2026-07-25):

# Licensing and third-party notices

Except where noted below, the original enclosure source, documentation, and
3D assets in this repository are available under the root [MIT license](LICENSE).
The charger-plug OBJ and STL assets were created by the repository owner and
are included in that grant.

## OpenSCAD Playground

`openscad_playground_container/openscad-playground` is a pinned fork of
[openscad/openscad-playground](https://github.com/openscad/openscad-playground).
It retains its upstream license notices. The upstream source is licensed under
GPL-2.0-or-later, and the compiled WebAssembly application is distributed under
GPL-3.0 because of the dependencies linked into it.

The files in `openscad_playground_container/patches/` modify that GPL-covered
application and are distributed under GPL-3.0. A deployed Playground is a
GPL-3.0-covered combined work; the root MIT license does not replace or narrow
those terms. The complete third-party license bundle is copied into every
published site as `LICENSE.md`, alongside a `SOURCE.md` identifying the exact
corresponding source revision.

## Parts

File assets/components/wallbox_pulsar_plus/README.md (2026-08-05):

# Wallbox Pulsar Plus body

`wallbox_pulsar_plus_body.scad` is an original, dimensionally scaled model of
the North American Wallbox Pulsar Plus enclosure. Its overall envelope and
profile proportions are derived from Wallbox's 2021 technical datasheet. The
bottom power-entry aperture is based on the North American installation guide.

The model uses inches and the repository's component coordinate convention:
`x` is vertical, `y` is horizontal, and `z` projects away from the mounting
surface. The included STL is generated from the SCAD source with:

```sh
openscad -o wallbox_pulsar_plus_body.stl wallbox_pulsar_plus_body.scad
```

Sources:

- [Pulsar Plus technical datasheet](https://support.wallbox.com/wp-content/uploads/ht_kb/2021/02/Pulsar_Plus_Datasheet.pdf)
- [Pulsar Plus North America installation guide](https://support.wallbox.com/na/knowledge-base/pulsar-plus-na-ig/)

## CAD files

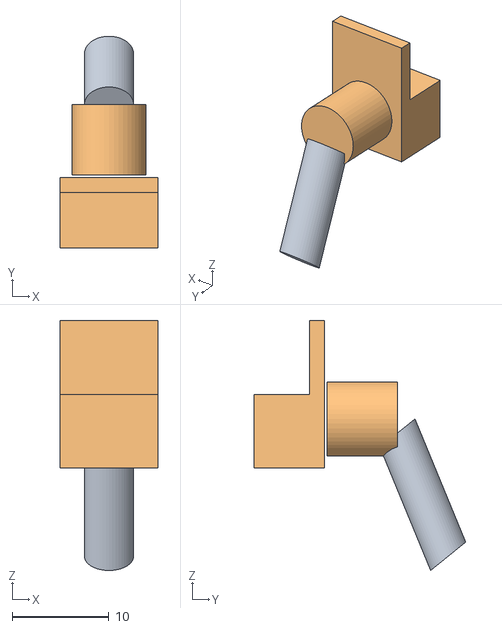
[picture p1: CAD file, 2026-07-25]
assets/components/ev_charger_plug/tinker.obj
10.2 x 21.8 x 25.8
obj_0
obj_1

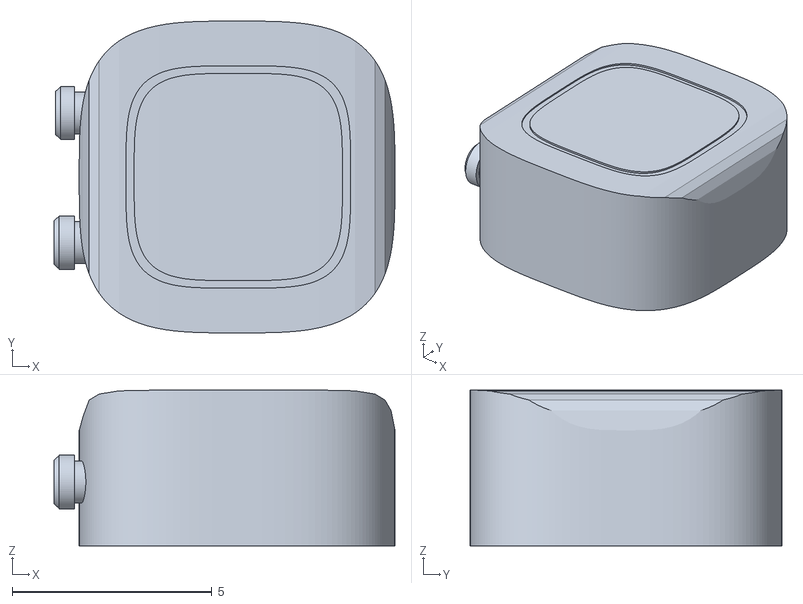
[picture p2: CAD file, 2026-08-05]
assets/components/wallbox_pulsar_plus/wallbox_pulsar_plus_body.stl
8.53 x 7.80 x 3.90

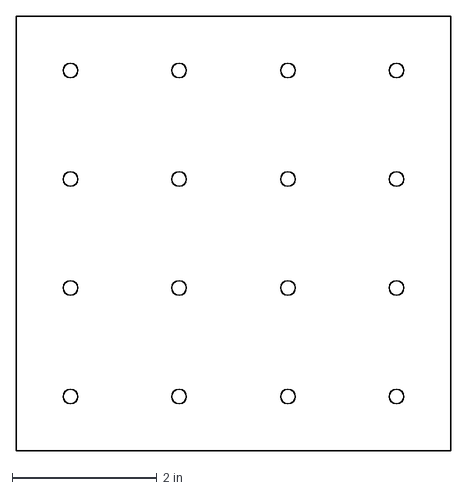
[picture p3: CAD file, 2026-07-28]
fabrication/gusset_plate_6x6.dxf
6.00 x 6.00 in

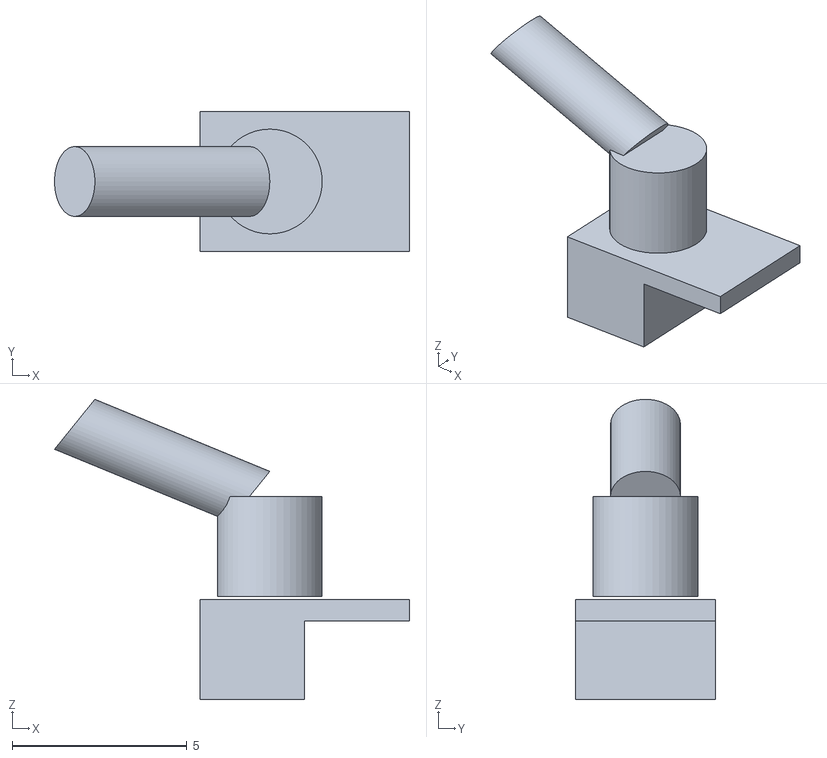
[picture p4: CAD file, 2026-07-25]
assets/components/ev_charger_plug/ev_charger_plug.stl
10.2 x 4.00 x 8.60

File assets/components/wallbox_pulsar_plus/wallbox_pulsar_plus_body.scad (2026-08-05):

// Dimensionally scaled Wallbox Pulsar Plus North America enclosure.
//
// Coordinate system matches ComponentType's local axes:
//   x = along / vertical, y = across / horizontal, z = out from the wall.
// Units are inches.  Overall body dimensions and profile proportions are
// derived from Wallbox's 2021 North American technical datasheet.  The
// 1.25-inch power aperture and 1-inch fitting recommendation come from the
// North American installation guide.

$fn = 72;

body_height = 7.9;
body_width = 7.8;
body_depth = 3.9;

power_port_from_left = 2.30;
charge_port_from_right = 2.26;
port_from_wall = 1.60;

function signed_power(value, exponent) =
    (value < 0 ? -1 : 1) * pow(abs(value), exponent);

function superellipse_points(
    height,
    width,
    exponent = 3.4,
    center = [0, 0],
    segments = 144
) = [
    for (angle = [0 : 360 / segments : 360 - 360 / segments])
        [
            center[0]
                + height / 2 * signed_power(cos(angle), 2 / exponent),
            center[1]
                + width / 2 * signed_power(sin(angle), 2 / exponent)
        ]
];

module front_profile(height, width, exponent = 3.4, center = [0, 0]) {
    polygon(points = superellipse_points(height, width, exponent, center));
}

// The side outline is normalized to the published 3.9-inch maximum depth.
// Intermediate stations follow the vector side profile in the datasheet.
side_profile = [
    [0.00, 0.00],
    [body_height, 0.00],
    [7.90, 2.89],
    [7.80, 3.39],
    [7.65, 3.65],
    [7.40, 3.80],
    [6.90, 3.88],
    [6.00, 3.90],
    [2.00, 3.90],
    [1.00, 3.88],
    [0.50, 3.80],
    [0.25, 3.65],
    [0.10, 3.25],
    [0.00, 2.89]
];

module side_profile_volume() {
    // Rotate an x/z polygon extrusion so it spans the local y axis.
    translate([0, body_width, 0])
        rotate([90, 0, 0])
            linear_extrude(height = body_width, convexity = 10)
                polygon(points = side_profile);
}

module enclosure_shell() {
    intersection() {
        linear_extrude(height = body_depth, convexity = 10)
            front_profile(
                body_height,
                body_width,
                center = [body_height / 2, body_width / 2]
            );
        side_profile_volume();
    }
}

module halo_groove() {
    // Scale-derived front bezel: about 5.56 x 5.62 inches, with an inner
    // halo/panel envelope of about 5.18 x 5.21 inches.
    translate([0, 0, body_depth - 0.055])
        linear_extrude(height = 0.075, convexity = 10)
            difference() {
                front_profile(5.62, 5.56, 4.0, [3.98, body_width / 2]);
                front_profile(5.21, 5.18, 4.0, [3.98, body_width / 2]);
            }
}

module vertical_gland(center_y, projection, outside_diameter) {
    // A three-stage envelope captures the lower boss/gland shown in the
    // dimensioned profiles while keeping the conduit centerline unobstructed.
    translate([-0.14, center_y, port_from_wall])
        rotate([0, 90, 0])
            cylinder(h = 0.75, d = 1.05);
    translate([-projection + 0.12, center_y, port_from_wall])
        rotate([0, 90, 0])
            cylinder(h = projection - 0.24, d = outside_diameter);
    translate([-projection, center_y, port_from_wall])
        rotate([0, 90, 0])
            cylinder(h = 0.14, d1 = outside_diameter * 0.82, d2 = outside_diameter);
}

union() {
    difference() {
        enclosure_shell();
        halo_groove();
    }

    // Physical left is local across-max when the unit is mounted on the
    // enclosure's front face.
    vertical_gland(body_width - power_port_from_left, 0.59, 1.33);
    vertical_gland(charge_port_from_right, 0.63, 1.34);
}

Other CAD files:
old/enclosure.scad
old/lumber.scad

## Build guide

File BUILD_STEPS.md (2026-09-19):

# EV Charger Enclosure Build Steps

This guide describes the modeled construction sequence for the fixed enclosure
design: 24-inch left-to-right post center spacing, 18 3/8-inch front-to-back post
center spacing, 47 inches above grade, and 32 inches of each post below grade.
Dimensions and cut lengths below apply to this design only.

The generated BOM and cut list remain the authoritative material references
for generated modeled materials. The custom tambour curtain, printed tracks,
webbing, pulls, and associated hardware remain prototype-controlled and are documented
separately in [`TAMBOUR_DOOR.md`](TAMBOUR_DOOR.md); they are not yet included in
the generated material outputs.

The top-plane bracing decision, site load screen, and required connection
capacity are documented in [`TOP_BRACING.md`](TOP_BRACING.md).

Except for the modeled custom top-bracing detail, this guide does not define
fastener length, structural connection capacity, concrete work, or the means and
methods for excavation or underground work. It does require
the modeled underground conduit and site restoration to be completed before
the enclosure posts are installed. Have the structure, electrical design,
conductor ampacity, grounding and bonding, box fill, permits, and installation
verified for the site and applicable code. Electrical work should be performed
by a qualified installer.

## Naming and visualization contract

- `fl`, `fr`, `bl`, and `br` mean front-left, front-right, back-left, and
  back-right.
- The `New model objects` block in every step contains exact identifiers from
  the Python model. These blocks are intended to be machine-readable.
- Every modeled object is introduced in exactly one step. The ground plane is
  permanent context and is not assigned to a step.
- Temporary operations such as removing and protecting the tambour curtain
  after its trial fit are not separate model objects. From its introduction in
  Step 12, the visualization shows the completed tambour door in its nominal
  open position.
- The OpenSCAD `build_step` parameter behaves as follows:
  - `build_step = 0`: show only permanent context, including the ground plane.
  - `build_step = 1..27`: show earlier objects normally, highlight objects from
    the selected step, and hide objects from later steps.
  - `build_step = 28`: show the completed model in its normal colors.
- An invalid positive step number should fail clearly during generation rather
  than silently display an incomplete or misleading model.

## 1. Complete the underground conduit risers and restore grade (`underground-risers`)

Before installing any posts, establish the enclosure layout from protected
reference points and mark all four 10-inch footing circles. Route both
underground conduit runs through the enclosure interior and clear of the full
footing excavations before sweeping them up to the risers. Bring the modeled
1 1/4-inch power riser out of the ground on the EV charger's conduit-port axis
(x = 15.35 inches and y = 11.2875 inches in the default model) and bring the
modeled 3/4-inch low-voltage riser out beneath the center of its junction box.
Its default axis is centered on the box bottom at x = 12 inches and
y = 4.1875 inches, clear of the post footings. This nominal centered location
preserves adjustment margin in every plan direction when the box opening is
field-located from the as-built riser. Leave both upper ends positioned for the
later equipment connections.

Before covering the conduit, measure and photograph its centerline, depth, and
the complete envelope of every sweep from protected reference points. Establish
two parallel witness lines that bound a no-auger corridor along each run. Drive
the witness stakes outside the trench and excavation area at intervals of a few
feet, connect them with taut string or marking paint, and record enough offsets
to reconstruct the lines if they are disturbed. Do not place closely spaced
stakes beside the conduit or where they would interfere with compaction. Mark
the sweep envelopes separately; a surface riser axis alone does not locate the
underground bend. Install detectable warning tape and, where appropriate for a
nonmetallic raceway, an approved tracer wire above the conduit.

Complete the required underground inspection before covering the work. Place
clean selected material around and above the conduit so angular or oversized
backfill cannot bear directly against it. Backfill the remainder of the trench
at suitable moisture and mechanically compact it in thin lifts, keeping the
fill balanced around the conduit and the risers plumb. Restore a level local
grade, preserve or reconstruct the witness lines from the recorded references,
and correct and recompact any later settlement before excavating the posts. A
period of watering and observation may reveal settlement, but it does not
replace lift compaction.

Reconfirm both stub-up locations, keep them plumb, cap or otherwise protect
their open ends, and guard them against movement or damage during post
excavation and framing. Burial depth, trenching, conductor or cable
installation, separation, marking-system materials, and the underground supply
design remain outside the model and must follow the approved site design.

New model objects:

```text
power_ground_riser
low_voltage_ground_riser
```

## 2. Install the four posts (`posts`)

Excavate and fill four 10-inch-diameter gravel footings from 36 inches below
the nominal ground datum to grade, centered on the post centerlines. Position
the four 79-inch 4x4 posts on the 24-by-18 3/8-inch centerline rectangle. The
model places each post 32 inches below grade and 47 inches above grade, leaving
4 inches of gravel beneath it.

**Before rental day:** Complete the required utility locate and compare each
entire footing circle with the preserved no-auger corridors and recorded
conduit and sweep locations. A marking system establishes location; it does not
make an inadequate clearance safe. Plan to use the auger only where the
complete 10-inch excavation, including a practical allowance for setup error,
bit drift, and soil breakout, remains outside the marked corridor. Plan to
hand- or vacuum-excavate where a sweep is too close, the recorded clearance is
insufficient, or the markings cannot be reliably reconstructed.

Obtain a sheet of structurally rated exterior plywood and prepare four
individual covers with generous bearing beyond the 10-inch holes. Size and
reinforce them to support at least twice the greatest person, equipment, or
material load that could be placed on them. Prepare a way to secure each cover
against wind and accidental displacement without driving an anchor into a
conduit corridor. Mark each cover conspicuously with `HOLE` or `COVER`, and
stage a barricade for the entire footing area. Individual covers are preferred
to one broad panel because one person can handle them, each can be inspected
and secured independently, and they do not have to pass over the conduit
risers.

**Auger day:** Using the 10-inch bit, excavate all four holes during the rental
period. Keep the auger and spoil loads off the restored conduit trench where
practical, and stop if unexpected fill, warning tape, or movement of a riser is
observed. Check every hole for center position, depth, bit drift, soil breakout,
loose material, and wall collapse. Verify that the witness markings and both
risers remain undisturbed. Install and secure each prepared cover as soon as
its inspection is complete, erect the barricade, and return the auger. Do not
leave an open hole unattended or rely on an unsecured sheet, tarp, or loose
boards as a cover.

**Post-installation day or days:** Inspect the covers and holes before resuming
work, particularly after rain, irrigation, freezing, or other changed site
conditions. Remove only the covers needed for active work. Place 4 inches of
compactable angular crushed aggregate beneath each post, then set and
temporarily brace all four posts so their spacing, diagonals, and plumb can be
adjusted together. Place the remaining aggregate evenly around all four sides
of each post in thin lifts, tamping each lift with a narrow tool before adding
the next. Complete every footing to grade and verify that the posts and both
conduit risers have not moved. Do not use rounded pea gravel.

Check the center spacing in both directions, compare the two plan diagonals,
and verify every post is plumb. Establish the front, back, left, and right
orientation now; all later part names depend on it. Maintain the temporary
external bracing until the permanent top bracing is installed and its frame
and connections are approved and stable. Continue to protect the two conduit
stub-ups throughout excavation, setting, and tamping.

New model objects:

```text
post_fl
post_fr
post_bl
post_br
footing_fl
footing_fr
footing_bl
footing_br
```

## 3. Add the complete top bracing (`top-bracing`)

Install 2x4 front and back perimeter braces and top-flush 4x4 left and right
braces. The back-left and front-right posts stop at `z = 46.25`; do not rabbet
them. Route only the four side-brace regions listed in
`output/fabrication.csv` to a uniform 3/4-inch depth. Dry-fit the approximately
35.133-inch-long rectangular blank cut from a stress-rated nominal 1x6; cut it
slightly long rather than rounding the minimum downward. Rip it slightly proud
of the calculated 4.907-inch minimum finished width, fit it on the modeled
post-center line, and jigsaw the end profiles listed in `output/fabrication.csv`.
Its full section must occupy `z = 46.25` to `47.00`, cover both complete post
tops, and stop at their exterior XY faces.

Install one laser-cut 6-by-6-by-0.074-inch G90 galvanized-steel gusset at each
involved corner. Orient each square from the two exterior post faces toward the
frame interior so it covers the post, both adjoining side braces, and the
diagonal. Install #9 pan-head screws in all sixteen modeled holes per plate.
Fastener length is intentionally not specified by this model; select it as part
of the approved structural connection detail. Seat every head without
overdriving and verify that every screw location has solid wood beneath it.

Before fastening the permanent bracing, reconfirm that every post is plumb and
compare the frame diagonals. Install the braces without pulling the posts out
of alignment, then repeat the plumb and square checks. Use the species and
grade specified against the 798-pound ASD brace demand in `TOP_BRACING.md`.
Reject split routed edges, stripped screws, raised plate edges, or rocking
hardware. Remove temporary external bracing only after the permanent frame and
both complete gusset assemblies are inspected and stable.

New model objects:

```text
brace_fl_fr
brace_fl_bl
brace_bl_br
brace_fr_br
brace_bl_fr
gusset_back_left
gusset_front_right
```

## 4. Add the lower side rails (`lower-side-rails`)

Install the 14 7/8-inch `rail_lb` and `rail_rbu` 2x4 rails between their front
and back posts. Their modeled bottom elevation is 12 1/4 inches above the
nominal ground datum. Install the secondary right-side `rail_rb` with its
modeled bottom at 7 1/4 inches. Keep all three wide faces horizontal.

Check that `rail_lb` and `rail_rbu` are level with one another, that `rail_rb`
is level at its separate elevation, that the clear spacing between posts
remains 14 7/8 inches, and that all four posts remain plumb. Adjust the temporary
bracing rather than using these rails to pull the posts into place.

New model objects:

```text
rail_lb
rail_rb
rail_rbu
```

## 5. Add the lower front cross rail (`lower-front-rail`)

Install the 20 1/2-inch `rail_fb` between `rail_lb` and `rail_rbu`. Its modeled
front face is offset toward the enclosure interior to support the front center
rail. The conduit boxes and fittings retain their absolute modeled coordinates
while their eventual mounting arrangement is deferred.

Check that it is level, square to the side rails, and correctly oriented before
adding the vertical member in Step 9.

New model objects:

```text
rail_fb
```

## 6. Add the front tambour supports (`tambour-vertical-rails`)

Install `rail_ltam` and `rail_rtam` vertically between `rail_lb`/`rail_rbu` and
the undersides of the top side 4x4s. Their modeled Y range is 4 1/4 to
5 3/4 inches, centered on the `y = 5` track datum. Use the full-size track
template to keep the two mounting faces parallel and directly opposite one
another.

Check both vertical rails for plumb, verify the modeled 20 1/2-inch spacing
between the left and right track mounting faces, and preserve access for the
plywood bend backers installed in Step 10.

New model objects:

```text
rail_ltam
rail_rtam
```

## 7. Add the side receiver rails (`upper-side-rails`)

Install `rail_lt` and `rail_rt` from the corresponding front tambour support to
the back post; their modeled lower and upper faces are at `z = 40 7/8` and
`42 3/8` inches. Keep both wide faces horizontal.

Check the receiver rails for level and confirm that the two upper rails remain
opposite one another. Their front ends depend on the plumb tambour supports
installed in Step 6, and their aligned inside faces receive `rail_ft` in
Step 8.

New model objects:

```text
rail_lt
rail_rt
```

## 8. Add the upper front cross rail (`upper-front-rail`)

Install the 20 1/2-inch 2x4 `rail_ft` between `rail_lt` and `rail_rt`, with its
lower and upper faces at `z = 40 7/8` and `42 3/8` inches. Its modeled Y range
is `6 3/16` to `9 11/16` inches. Fasten its complete end faces to the side
rails; the former separate vertical header-support blocks are not used.

Check the header for level and square and verify its position before adding
`front_center_rail`. Use connections designed for the charger dead load and
the repeated lateral and torsional loads produced while handling its cord.

New model objects:

```text
rail_ft
```

## 9. Add the main vertical rails (`main-vertical-rails`)

Install `front_center_rail` between `rail_fb` and `rail_ft`. Install
`right_center_rail` between `rail_rbu` and `rail_rt`.

Check both rails for plumb. Their face orientation matters: the front center
rail supports the power junction box and EV charger, while the right center
rail supports the outlet backers, Wi-Fi access point, and low-voltage paths.

New model objects:

```text
front_center_rail
right_center_rail
```

## 10. Add the plywood tambour bend backers (`tambour-bend-backers`)

Fit a 3/4-inch plywood backer behind the top of each vertical tambour rail.
Each piece occupies `y = 5 3/4` to `7 1/4` inches and `z = 42 3/8` to
`43 1/2` inches. The left piece occupies `x = 2 3/4` to `3 1/2` inches; the
right piece occupies `x = 24` to `24 3/4` inches. This placement fills the
concave track-backing gap without overlapping `rail_lt` or `rail_rt`.

Keep each plywood face flush with the track mounting plane and the underside of
the corresponding top 4x4. Verify the complete front bend footprint against
the full-size track template before fastening either piece.

New model objects:

```text
left_tambour_bend_backer
right_tambour_bend_backer
```

## 11. Install and set the tambour tracks (`tambour-track`)

Follow [`TAMBOUR_DOOR.md`](TAMBOUR_DOOR.md) to complete the full-size prototype
and approve the 1/2-by-3/4-inch slat profile, printed pulls, mechanical webbing,
track profile,
loading sections, and end stops before installing production parts. Mount the
mirrored ASA track segments along the modeled paths before installing any nearby
electrical equipment or conduit. Their final position is the controlling
clearance datum for the power-junction assembly, its 1 1/4-inch conduit, and
all outgoing conduit runs; do not use those later assemblies to force or shift
a guide. The track datums' rear lower endpoint is at `y = 21`, `z = 3` inches;
their front lower endpoint is at `y = 5`, `z = 16` inches; their top
centerline is at `z = 44 3/8` inches; and both turns begin from a modeled
2 5/8-inch centerline radius. The slat center shares the running-groove datum;
the wood is rendered at its actual 1/2-inch depth while the complete hardware
assembly must remain inside the 1 1/2-inch clearance envelope.

Protect the fixed tracks from debris, finish, and damage during the remaining
work. Before proceeding, lock the fixed guide geometry, record its critical
spacing, and use the installed guides and those measurements when checking
every nearby box and conduit clearance.

New model objects:

```text
enclosure_tambour_track
```

## 12. Load and trial-fit the tambour door (`tambour-door`)

Load the completed curtain and cycle it fully using both the lowest pull slat
and the printed pull approximately 18 inches above it. Verify equal tracking,
the approved operating force, clearance from every installed framing member,
and at least 1/4-inch clearance from the installed top bracing using the
approved curtain and pull-slat envelope. Mark all matched track parts, then
remove the curtain, removable loading sections, and end stops. Protect the
fixed tracks from debris, finish, and damage during the remaining work.

The build-step visualization shows the completed door in its nominal open
position from this step onward; it does not depict this temporary removal.

New model objects:

```text
enclosure_tambour_door
```

## 13. Verify the consolidated tambour top supports (`tambour-top-rails`)

Verify that the inside faces and undersides of the two top side 4x4s provide
continuous, level attachment surfaces for the printed tracks and removable
ceiling retainers. Preserve the modeled rear and front bend clearances and
confirm the support geometry against the prototype alignment gauges.

After the tambour trial fit, trial-fit the removable ceiling panel against its
independent retainers, then remove it until the services and tambour have passed
their later clearance checks.

New model objects:

```text
tambour_ceiling_panel
```

## 14. Add the street-light backing (`street-light-backing`)

Install the three 20 1/2-inch front backing 2x4s. The bottom backer starts at a
modeled elevation of 33 inches, the middle backer at 36 1/2 inches, and the
upper backer at 40 inches. Their rearward face position locates the outlet-box
stack relative to the siding, and the bottom backer supports the horizontal
street-light conduit run.

Check that the backers are level, form a continuous field from z = 33 through
43 1/2 inches, and share the modeled street-light centerline at
x = 13 3/4 inches. The outlet box remains centered at z = 40 inches.

New model objects:

```text
front_street_light_backer_bottom
front_street_light_backer_lower
front_street_light_backer_upper
```

## 15. Mount the EV charger with its cord and plug (`ev-charger-mounting`)

Mount the EV charger body and its inseparable flexible cord and plug on
`front_center_rail`, with the charger body shifted 2 inches downward from its
former modeled position while the cord holster remains fixed. Confirm and
record the physical location of its conduit
input; this installed position controls the field-fit conduit connection in
Step 17. Route the cord between the charger body, storage position, and
ground-level reach shown by the model.

Check the flexible cord for strain relief, minimum bend radius, storage
clearance, tambour-door clearance, and absence of abrasion or pinch points.
Cycle the tambour fully from both printed pulls and confirm that neither the
door nor either pull contacts the charger, cord, or plug. Repeat these checks
after making the power connection in Step 17 and after reloading the curtain in
Step 25.

New model objects:

```text
front_ev_charger_body
front_ev_charger_plug
front_ev_charger_cable
```

## 16. Preassemble and mount the power junction (`power-junction-assembly`)

Before mounting the Carlon E987N power junction box, fit its rear-facing
1 1/4-inch input adapter and coupling for the T-body branch and the two
right-side 1/2-inch light and receptacle outlets.
The light outlet is forward of the receptacle outlet. Then mount the connected
box on `front_center_rail`, spanning x = 15 to 19 inches in the default model,
and y = 2.1875 to 6.1875 inches. Its bottom face remains at the modeled
elevation of approximately z = 6.50 inches. Keep every fitting axis aligned
with its conduit path.

Check that the fittings are fully seated and clear of `front_center_rail`.
Keep the rear fitting aligned with the raised 1 1/4-inch feed from the T body.

The #6 charger group continues vertically through the T body and bypasses the
junction box. The #12 supply group branches through the T into the box, where
its hot/hot/neutral conductors feed separate light and outlet hot/neutral pairs
and the #12 equipment grounds are spliced. The modeled junction-box calculation
is 18.00 in³ against an assumed 49.00 in³ marked capacity. Verify the marking
on the installed box and the locally required calculation before construction.

New model objects:

```text
power_junction_box
power_junction_input_adapter
power_junction_input_coupling
power_junction_light_adapter
power_junction_light_coupling
power_junction_outlet_adapter
power_junction_outlet_coupling
```

## 17. Connect the power junction to the EV charger (`ev-charger-power`)

Using the physical charger-input position recorded in Step 15, align the
1 1/4-inch ground riser and T body with the charger's conduit-port X coordinate.
Set the T-body branch high enough that the complete conduit envelope passes
above `rail_fb`, then run the full horizontal branch to the rear coupling on
the junction box. Fit the reducer at the T body's upward outlet and run the
straight 1-inch conduit to the bottom of the charger.

Check alignment at the riser, junction box, top adapter and coupling, and
charger entry. Route the unspliced #6 charger group through this conduit
according to the approved electrical design. Verify that the power path remains
clear of the cord-storage volume. Check the flexible cord for strain relief,
minimum bend radius, storage clearance, tambour-door clearance, and absence of
abrasion or pinch points. Cycle the tambour fully from both printed pulls and
confirm that neither the door nor either pull contacts the completed power
connection, charger, cord, or plug. Verify the installed product markings and
locally required bend and fill calculations before construction. Repeat the
clearance check after the curtain is reloaded in Step 25.

New model objects:

```text
power_ev_charger_feed
power_ev_reducer
power_ev_t_body
power_t_junction_feed
```

## 18. Rough in the street light (`street-light-rough-in`)

Mount the Commercial Electric WRB550B base box on the street-light backers.
Install the 1/2-inch feed from the forward fitting on the positive-X side of
the power junction box. Run toward positive X and make the first modeled
2 1/2-inch-radius sweep upward against the negative-X face of `post_fr`. Make the
required Y transition gradually on this long rising leg. At z = 34 inches,
make the second 3-inch-radius sweep toward negative X, support the horizontal
run on the bottom backer, and make the third 3-inch-radius sweep toward
positive Z into the bottom port of the WRB550B base box at x = 13.75,
y = 1.5, and z = 37.3 inches. The junction-box fitting center is at
y = 3.1875 inches, leaving approximately 0.14 inch between the conduit
envelope and the closed tambour plane.

Check that the box is centered at x = 13 3/4 inches and z = 40 inches, the
unused side and top ports are plugged, the horizontal run is securely strapped
to its backing, and the conduit stays forward of the open tambour door at
y = 5 inches. Pull and terminate the light branch's #12 conductors only
under the approved wiring design.

New model objects:

```text
front_street_light_base_box
power_street_light_feed
```

## 19. Add the backing and rough in the right-side outlet (`outlet-rough-in`)

Install the two 6 11/16-inch 2x4 backers between `right_center_rail` and
`post_br`. Their modeled lower-face elevations are approximately 13 5/8 and
18 7/8 inches. Check that both backing faces are coplanar at x = 26.45 inches;
this plane sets the rear of the 2.30-inch-deep FSE outlet box and its final
projection through the siding.

Immediately after securing the backing, mount the Carlon E980DFN FSE box and
install the 1/2-inch feed from the junction box, including both modeled
4-inch-radius sweeps into the bottom hub.

Check that the box/cover mating plane will finish at x = 28.75 inches, roughly
1/4 inch beyond the siding, and that the hub center is at x = 27.016 inches.
Confirm conduit clearances before covering the framing. Pull and terminate the
outlet branch's #12 conductors only under the approved wiring design.

New model objects:

```text
back_right_outlet_backer_lower
back_right_outlet_backer_upper
back_right_outlet
power_back_right_outlet_feed
```

## 20. Add the low-voltage termination (`low-voltage-termination`)

Mount the low-voltage junction box in its shifted position, spanning x = 10
to 14 inches and y = 2.1875 to 6.1875 inches, centered at z = 13 inches. The
power junction spans x = 15 to 19 inches, so both boxes share the same
positive-Y face and retain a one-inch X gap. Future backing lumber may be
added but is not included. Connect the center of the bottom panel to the
3/4-inch riser installed in Step 1, field-locating the opening from the
as-built riser position. Then add the three cable glands in the remaining
bottom-panel area; reposition their nominal front-row layout as necessary to
preserve fitting clearances.

Keep each fitting center at least 3/4 inch from the panel sides. Confirm that
the riser remains plumb and clear of the 10-inch footing and that the existing
cables have room to leave the forward glands in negative Z before sweeping
toward the center framing. Route the blue Cat 6 feeds beside the 3/4-inch
riser, retaining the modeled clearance. Use
the modeled 0.625-inch upward turn beneath the glands, remain on the negative-Y
side of `rail_fb` until above it. Use the gentle departure spline modeled for
the dark-brown street-light cable; it bottoms at z = 8.25 inches without a flat
horizontal run.

New model objects:

```text
low_voltage_termination_box
low_voltage_input_adapter
low_voltage_cable_gland_1
low_voltage_cable_gland_2
low_voltage_cable_gland_3
```

## 21. Mount and cable the Wi-Fi access point (`wifi-and-feed`)

Mount the Wi-Fi access point near the top of `right_center_rail`. Route the
highest-X low-voltage gland's cable through the modeled droop, then sweep it
gradually in positive X as it rises toward `front_center_rail`. Reach the
positive-X face near z = 10.25 inches, hold that X coordinate while sweeping to
the rail's center Y coordinate near z = 15 inches, carry it straight upward,
and bend around
the positive-Y face of the rail near the top, cross in positive X along the
positive-Y face of `rail_ft`, and descend the negative-X face of
`right_center_rail`. Just below the access point, bend around the rail's
positive-Y face and sweep upward into the existing bottom entry.
Identify this run as blue Cat 6 cable in accordance with the model.

Check that the cable retains at least the modeled 0.625-inch minimum bend
radius and remains clear throughout the tambour door's travel.

New model objects:

```text
front_wifi_access_point
low_voltage_wifi_feed
```

## 22. Route the street-light service cable (`light-service-cable`)

Route the front low-voltage gland's cable downward before sweeping toward and
up the positive-X face of `post_fl`. Continue beneath `brace_fl_fr` and
approach the mirrored service loop above the street-light box stack from the
negative-X direction. The loop returns in that direction before terminating
at the existing conduit entry.
The model renders this low-voltage cable dark brown.

Check attachment clearances, the 1 1/4-inch service-loop radius, the overall
0.625-inch minimum bend radius, clearance from the street-light backing, and
separation required by the approved wiring design.

New model objects:

```text
low_voltage_street_light_service
```

## 23. Route the charger low-voltage feed (`charger-low-voltage-feed`)

Route the center low-voltage gland's cable down from the gland and up the
negative-X face of `front_center_rail`. Sweep it in positive X through the
droop and ascending return to bypass the centered 3/4-inch riser, then continue
toward the rail. As it approaches
the elevation of the EV charger's bottom plane, bend in positive Y to clear the
positive-Y face of the rail, then sweep upward into the charger's unchanged
bottom entry.
Identify this run as blue Cat 6 cable in accordance with the model.

Check its direct entry sweep, the 0.625-inch minimum bend radius, and clearance
from the tambour door, power conduit, and siding through the door's full
travel.

New model objects:

```text
low_voltage_ev_charger_feed
```

## 24. Install the composite siding (`composite-siding`)

Before placing the top boards, install 1/4-inch ripped pressure-treated shims
on the exposed portions of all four perimeter members and across both
non-gusseted corner posts. Keep the shims level and terminate them at the custom
gusset envelopes so no shim rests on a plate or pan head. Let the decking span
these short interruptions, and leave drainage paths at the plate edges. Use
roof fasteners long enough to
retain the originally required penetration after passing through the shims.

Install the composite boards only after the framing, tambour guides, interior
equipment, conduit, and cable routes are installed, inspected, and proven clear
through the door's full travel. Only siding trim, tambour reloading, and the
fixtures or covers that mount outside the siding follow this step.

The model represents 48 physical cuts as 57 rendered pieces because
boards interrupted by the street-light and outlet openings, and the top rear
board surrounding the tambour opening, are split into multiple solids.

Maintain the modeled bottom elevation of 2 inches and the front-light,
right-outlet, and rear-tambour openings. Dry-fit opening courses before cutting
and confirm the electrical boxes' finish projections. The current BOM totals
870 3/4 inches of composite decking and allocates five 16-foot stock boards.

New model objects:

```text
roof_shim_brace_fl_fr
roof_shim_brace_fl_bl
roof_shim_brace_bl_br
roof_shim_brace_fr_br
enclosure_siding_top_1
enclosure_siding_top_2
enclosure_siding_top_3
enclosure_siding_top_4
enclosure_siding_front_1
enclosure_siding_left_1
enclosure_siding_right_1
enclosure_siding_rear_top_left
enclosure_siding_rear_top_header
enclosure_siding_rear_top_right
enclosure_siding_front_2_1
enclosure_siding_front_2_2
enclosure_siding_front_2_3
enclosure_siding_front_2_4
enclosure_siding_left_2
enclosure_siding_right_2
enclosure_siding_rear_left_2
enclosure_siding_rear_right_2
enclosure_siding_front_3
enclosure_siding_left_3
enclosure_siding_right_3
enclosure_siding_rear_left_3
enclosure_siding_rear_right_3
enclosure_siding_front_4
enclosure_siding_left_4
enclosure_siding_right_4
enclosure_siding_rear_left_4
enclosure_siding_rear_right_4
enclosure_siding_front_5
enclosure_siding_left_5
enclosure_siding_right_5_1
enclosure_siding_right_5_2
enclosure_siding_right_5_3
enclosure_siding_rear_left_5
enclosure_siding_rear_right_5
enclosure_siding_front_6
enclosure_siding_left_6
enclosure_siding_right_6_1
enclosure_siding_right_6_2
enclosure_siding_right_6_3
enclosure_siding_rear_left_6
enclosure_siding_rear_right_6
enclosure_siding_front_7
enclosure_siding_left_7
enclosure_siding_right_7
enclosure_siding_rear_left_7
enclosure_siding_rear_right_7
enclosure_siding_front_8
enclosure_siding_left_8
enclosure_siding_right_8
enclosure_siding_rear_left_8
enclosure_siding_rear_right_8
enclosure_siding_front_9
enclosure_siding_left_9
enclosure_siding_right_9
enclosure_siding_rear_left_9
enclosure_siding_rear_right_9
```

## 25. Install the siding trim and reload the tambour (`siding-trim`)

Install the paired black-aluminum angle legs at all four enclosure corners and
both sides of the tambour opening, then install the paired header legs. The
vertical trim pieces are modeled at 46 inches; the rear opening header is
20 1/2 inches.

Check the trim for plumb, straight edges, safe cut edges, and interference-free
clearance around the tambour opening. Uncover and clean the fixed ASA tracks,
then recheck their spacing and joints in case the siding or trim moved them.
Reload the curtain through the removable lower-rear sections and reinstall the
end stops. Cycle the door fully from both printed pulls and repeat the
operating-force, tracking, endpoint-retention, and framing/trim clearance tests
from [`TAMBOUR_DOOR.md`](TAMBOUR_DOOR.md). Repeat the full-travel clearance
check against every completed conduit and fixed cable route. Install the
removable 20 1/2-by-7 15/16-inch, 1/4-inch plywood ceiling panel on independent
retainers at z = 43 1/4 to 43 1/2 inches beneath the overhead curtain, then
repeat the full-travel test before placing the enclosure in service.

New model objects:

```text
enclosure_siding_angle_front_left_a
enclosure_siding_angle_front_left_b
enclosure_siding_angle_front_right_a
enclosure_siding_angle_front_right_b
enclosure_siding_angle_rear_left_a
enclosure_siding_angle_rear_left_b
enclosure_siding_angle_rear_right_a
enclosure_siding_angle_rear_right_b
enclosure_siding_angle_tambour_left_a
enclosure_siding_angle_tambour_left_b
enclosure_siding_angle_tambour_right_a
enclosure_siding_angle_tambour_right_b
enclosure_siding_angle_tambour_header_face
enclosure_siding_angle_tambour_header_bottom
```

## 26. Finish the street-light assembly (`street-light-finish`)

Install the WRE450G extension ring through the siding opening, with its front
face flush with the siding exterior plane, then attach the downward-facing
street-light fixture.

Check the gasketed/weatherproof assembly, unused-port plugs, fixture alignment,
and siding clearance. Complete conductor termination and testing under the
approved electrical design.

New model objects:

```text
front_street_light_extension_ring
front_street_light
```

## 27. Finish the right-side outlet (`outlet-finish`)

Install the Intermatic WP5100BL in-use cover on the FSE box after the siding is
complete.

Check the cover gasket, weatherproof mating surface, full opening range, and
finished projection. Complete receptacle installation, conductor termination,
and testing under the approved electrical design; the receptacle itself is not
modeled.

New model objects:

```text
back_right_outlet_cover
```

## Model coverage checklist

The 27 steps above assign all modeled construction objects exactly once:

| Category | Modeled count | Assigned steps |
| --- | ---: | --- |
| Lumber members | 25 | 2-9, 14, 19 |
| Components and fittings | 31 | 3, 10, 13, 15-21, 24, 26-27 |
| Conduit runs | 6 | 1, 17-19 |
| Cable paths | 4 | 15, 21-23 |
| Tambour track and door | 2 | 11-12 |
| Composite siding render parts | 57 | 24 |
| Siding trim render parts | 14 | 25 |

The `ground` object is visualization context rather than an installed enclosure
component, so it intentionally remains outside the numbered sequence.

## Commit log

2026-07-25 Initial public release
    [enclosure.scad, ev_charger_plug.stl, lumber.scad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]
2026-07-25 Add preview coordinate grid controls
    Add an optional one-inch XY grid at a configurable Z location.
    Compute its bounds from all non-ground model geometry and add one
    inch of margin on every side.
    Distinguish five- and ten-inch coordinates with progressively
    stronger colors and line widths. Keep the grid preview-only so model
    exports remain unchanged. Hide the ground disk by default behind a
    Customizer toggle so it does not obscure the grid.
    Protect automatic Playground deployment by requiring a clean working
    tree and a checked-out commit that exactly matches its freshly fetched
    upstream. Unsafe builds still write local outputs, but they skip the
    Pages push and report a warning.
    Add regres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
2026-07-28 custom gusset
    [gusset_plate_6x6.dxf]
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2026-07-31 fix tambour track x dir mounting
2026-07-31 adjust tambour track clearance
2026-08-04 framing, tambour-track refactor
    Front track moved to derived y = 5.0, retaining 0.325-inch electrical
    backer clearance.
    rail_ft now spans rail_lt and rail_rt; hard-coded HEAD placement
    values were replaced with frame/tambour-derived calculations.
    Retained two 1½-inch bend backers, preserving full flange support.
    Fabrication runs now derive from resolved geometry: 38.75-inch rear,
    10.75-inch top, 25.75-inch front.
    Reworked Steps 4–9 and synchronized the tambour and top-bracing
    documentation.
    Updated parameterized, clearance, build-step, and output regressions.
2026-08-04 fix conflicts; individual object visibility
    Added individual OpenSCAD toggles for every lumber member and
    component.
    Replaced conflicting bend backers with mirrored 3/4-inch plywood
    components.
    Trimmed the tambour guard to rail_ft’s positive-Y face.
    Added explicit 0.325-inch street-light/handle clearance regression
    coverage.
    Split tambour track and door into separate objects and build steps.
    Updated the sequence to 27 steps and synchronized documentation.
2026-08-05 model wallbox body
    [wallbox_pulsar_plus_body.scad, wallbox_pulsar_plus_body.stl]
2026-09-19 Revise enclosure rails and component anchoring
    Move the lower and tambour rails to the revised frame geometry,
    including the new upper-right lower rail. Add absolute world-space
    component anchors so conduit fittings and the charger retain their
    approved coordinates while their reference members change. Preserve the
    approved conduit and low-voltage route elevations independently of rail
    clearance.
    Update the build instructions and regression tests for the revised
    geometry, fixed elevations, and absolute-anchor validation.
2026-09-19 Anchor preview grids at front-left post
    Anchor the preview grid at post_fl's minimum XY corner so the
    coordinate system remains fixed at [0, 0] when enclosure dimensions
    change. Rename the origin regressions to describe their behavioral
    guarantees, and retain explicit checks for parameterized post and siding
    extents.
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2026-10-13 Defer tambour installation and revise track design
    Move tambour parts out of numbered construction steps and mark them as
    deferred reference objects with a model control for showing them.
    Update build steps and documentation to reflect the reduced scope.
    Revise track and slat fabrication for deeper channels, dependable slat
    capture, and removable joint collars and end stops. Add an HDPE fabrication
    plan and an X2D implementation task, and update the clearance, assembly,
    and refactoring notes.
    Update the model and tests for deferred-object visibility and revised
    build-step assignments and tambour fabrication dimensions.
2026-10-14 Reorder enclosure build steps for framing access
    Move street-light backing work after the charger and power-junction
    rough-in so those assemblies can be positioned and connected before
    the front backers restrict access. Add the right-side lower rail and
    center rail to the outlet rough-in step, where their installation
    precedes the outlet backers and wiring.
    Update the documented step numbers and model-to-step assertions to
    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
2026-10-14 Model low-voltage ground sweep elbows
    Model two Carlon 45-degree belled elbows to offset the low-voltage
    conduit toward negative X near grade, then continue the run vertically
    from the second elbow. Compute both fitting poses and conduit endpoints
    from resolved component geometry so the inlet, elbows, and riser align.
    Extend component geometry to accept arbitrary cylinder directions and
    explicit right-handed bases. Render rounded internal cylinder joints
    while preserving flat socket and spigot ends, and include these parts in
    component bounds and SCAD records.
    Document the fixed ground-entry coordinates and the two-elbow field
    installation sequence in the build steps.
2026-10-14 Align low-voltage box with upper elbow
    Place the low-voltage box and bottom adapter directly above the
    second 45-degree sweep elbow. Derive the box location and elevation
    from the elbow outlet, and remove the intervening vertical conduit
    segment. Offset the entry toward the back to leave room for the
    cable glands.
    Move the power junction box two inches left while preserving its
    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
2026-10-14 Add lower rails for power junction box support
    Rename the upper framing members for clarity and add matching lower
    side rails with a lower front cross rail. The lower frame sits one inch
    below the former right lower rail position and creates a support edge
    for the power junction box.
    Update the build-step guide and clearance analysis to describe the new
    member names and mounting arrangement, and revise build assertions for
    the renamed upper framing members.
2026-10-15 Add power conduit guard around T body
    Model a removable plywood bumper with two ripped 2x4 uprights
    anchored to the front rails. Derive its dimensions from the T body and
    rail positions, preserve a 1/4-inch clearance, and reject an upright
    depth that cannot be ripped from standard stock.
    Include the panel and screws in the fabrication and bill of materials
    outputs. Extend lumber members with a finished wide dimension so the
    ripped uprights render at their modeled depth and report the correct
    stock and finished widths.
    Document the installation sequence, fasteners, clearances, and fit
    checks. Advance the build guide to step 24 and update object coverage
    counts for the new guard assembly.
2026-10-16 Model the power junction with a Type TB body
    Replace the modeled Carlon Type T conduit body with the IPEX Scepter
    STB40S Type TB fitting. Define the catalog body and rear hub geometry,
    then route the riser, charger feed, and junction-box branch through its
    actual port locations.
    Update the conduit BOM, build-step guidance, clearance analysis, and
    layout references to use the new fitting and renamed model objects.
    Refresh geometry and build tests to match the Type TB component.
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2026-10-17 Model surveyed grade and level post tops
    Build a bilinear ground surface from the four surveyed post corners
    and use it for footing tops, cable clearance, and ground references.
    Keep all posts level at the front-left datum; fit the diagonal between
    the corner posts and update related framing elevations.
    Refresh build documentation and regression coverage for the survey,
    installed brace geometry, and resulting cut list.
2026-10-17 Replace Type TB body with shallow charger pull box
    Replace the IPEX STB40S Type TB body in the charger riser
    with a 4x4x2-inch pull box. Retain the 1 1/4-inch ground-
    riser entry, add a 1-inch top charger feed, and route a
    3/4-inch rear branch to the power junction. Model each cut-
    hole fitting with an exterior sealing washer and interior
    locknut, including light, outlet, and low-voltage box entries.
    Update the conduit model, hardware BOM, build steps, and
    clearance analysis to reflect the revised enclosure layout
    and fitting envelopes. Record unsourced generic fittings and
    clamping hardware in the BOM for final hardware selection.
    Revise build-step assignments and update the conduit-layou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
2026-10-18 Model Carlon charger pull box geometry
    Model the Carlon E989NNJ enclosure from its catalog dimensions, including
    the cover, rear wall, and minimum opening. Position its two-inch interior
    around the retained charger riser while keeping the top fitting aligned
    with the charger entry, and derive the back fitting from the box depth.
    Record the sourced junction box and updated installation dimensions in
    the BOM and build steps. Add geometry and placement assertions for the
    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
2026-10-18 Add TPU sealing rings for conduit adapters
    Generate seven TPU sealing rings for the enclosure’s modeled Carlon
    E943D–E943G adapters, matching all seven washer locations. Include STEP
    models by adapter and location, a combined seven-ring layout, editable
    sizing inputs, an inventory, and CAD validation results.
    Document Bambu X2D TPU preparation, starting slicer settings, fit checks,
    and prototype limitations. Include the dimension basis and Carlon source
    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
2026-10-19 Defer tambour guides and support header rails
    Connect the permanent side receiver rails directly between the posts so
    they carry the charger header before tambour installation. Defer the
    guide uprights, upper blocks, facings, and bend backers, preserving the
    rails and their continuous load path.
    Update the active build sequence and build-step assertions to match
    the shorter construction sequence. Revise the tambour installation,
    clearance, and bracing notes to document the split future supports
    and preserve access for their installation.
2026-10-19 Reorder build steps for low-voltage and guard
    Move the charger low-voltage feed and wood power-cord guard ahead of the
    street-light work, grouping the cable route with the low-voltage
    equipment and the removable bumper with the pull-box installation.
    Add the blue Cat 6 route from the center gland to the charger's existing
    bottom entry, with bend-radius and clearance checks. Document the
    guard's lumber and panel dimensions, fasteners, pull-box cover access,
    and trial-fit checks around the actual equipment and charging cord.
    Place street-light backing after the Wi-Fi and charger cable work, route
    the street-light service cable before rough-in, and keep finish work
    after siding. Renumber the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
2026-10-19 Install the power junction after charger rough-in
    Move the power junction assembly after the charger pull-box connection so
    its conduit branch can be laid out from the charger input position recorded
    in Step 9. Leave the branch end accessible during Step 10, then connect it
    to the junction box rear fitting while mounting that box in Step 11.
    Update the step references for rail support and charger power routing. Keep
    the fitting installation, conductor branching, and box-fill guidance with
    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
2026-10-19 Split outlet rough-in and seat conduit on rail
    Separate the right-side installation into distinct steps for the center
    rail, outlet box and backing, and outlet conduit. This makes the build
    sequence reflect when each component is installed and expands the model
    coverage from 23 to 25 steps.
    Lower the horizontal outlet-feed run to the top of the lower right rail
    while preserving the junction and outlet anchors. Derive the offset
    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
2026-10-19 Align outlet conduit with the lower rail
    Set the junction-box outlet adapter at the same elevation as the
    horizontal conduit run seated on the lower right rail. Keep the
    lighting adapter and conduit at the junction box centerline.
    Route the outlet feed directly from the adapter to the rear outlet
    and define its two modeled sweeps at the corresponding route points.
    Update the build steps and regression checks to describe and verify
    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
2026-10-19 Install right center rail before charger work
    Move right_center_rail from Step 12 to Step 9. This puts the rail ahead
    of the outlet backers and low-voltage work it supports. Renumber the
    charger mounting, charger power connection, and power junction steps,
    then update dependent step references.
    Keep the written procedure aligned with the model's intended assembly
    order and make the rail available before attached components are
    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
2026-10-21 Add a configurable front address plaque
    Model the copper 4754 plaque below the Brook fixture, with recessed
    black numerals and placement tied to enclosure dimensions. Include
    the plaque in build steps and the shopping list.
2026-10-23 Model revised Brook light and UF-B wiring
    Replace the provisional recessed box and low-voltage service loop with
    an interior transition box and a UF-B lighting branch routed through
    the new 1/2-inch siding bore.
    Mount the Brook bracket to the front brace and add four separate 4754
    numerals on a one-inch-thick support board. Remove the old street-light
    backers and low-voltage gland; update siding geometry, inventory, build
    instructions, and regression coverage.
2026-10-24 Model US09 siding and installation details
    Add US09 siding with provisional 130 mm course spacing, AW08 clip
    stand-off, board cuts, opening clearances, scribed lower edges,
    attachment stations, trim, and backing.
    Generate siding geometry, insect mesh, fabrication and shopping
    lists, installation metadata, and corner review models. Update the
    build sequence and document sample-fit checks and prototype
    assumptions that still need physical verification.
    Include the All Weather siding installation guide as a reference.
2026-10-24 Refine siding sequence and installation guide
    Move US46 corner trim installation ahead of the siding courses, and split
    course 1 into front and side boards plus the notched rear board. Renumber
    build steps and update coverage assertions for the revised sequence. Add the
    all-weather horizontal siding installation guide PDF.
2026-10-24 Replace US09 siding with US135 All Weather Pro
    Replace the US09 model and build integration with a dedicated US135
    All Weather Pro siding model. Update the enclosure renderer, build
    steps, README, and siding guide for the new product. Document that the
    preview uses schematic seams instead of V-groove machining, add US135
    regression coverage and a current takeoff CSV, and mark the old US09
    references in the refactor plan as historical.
2026-10-24 Model US135 direct fastening and applied trim
    Replace AW08/T-7 attachments with generated face screws at supported
    board locations. Give each physical board one fixed point and oversized
    sliding holes at the remaining attachments.
    Replace US46 corner and US44 opening profiles with applied US20 trim.
    Revise the wall and roof offsets so the boards seat directly against
    framing. Update installation guidance for the custom fastening sequence,
    clearances, drainage, and ventilation constraints.
    Generate a purchase BOM with the cut list, including revised stock counts
    and quantities for screws, trim, backing hardware, and mesh. Update the
    build-step model, siding documentation, and regression cov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
2026-10-24 Replace roof shims with plywood support strips
    Replace perimeter and diagonal shims with paired 3/4-inch PT plywood
    roof strips, and remove intermediate roof backing. Add routed 2x4
    supports beside the gussets with opposed toe screws and independent
    strip anchors.
    Update roof attachment geometry, BOMs, installation artifacts, and
    build instructions. Document provisional bearing, drainage and
    fastener assumptions, with regression coverage for the revised layout.
2026-10-24 Limit outlet backing to affected siding courses
    Limit added outlet backing and screw stations to the full heights of the
    siding courses intersected by the cutout. Keep regular wall supports
    above and below that local reinforcement.
    Update the enclosure model and regression coverage, then align the
    installation steps and bill of materials with the localized backing,
    generated screw schedule, and revised quantities.
2026-10-25 Conceal US135 wall fasteners in inverted overlaps
    Reverse wall profiles so the lower fastening lip bears against framing,
    then place the screw row near the middle of the overlap. Generate fasteners
    only where the head is supported and concealed by the next course or
    applied US20 trim; retain explicit exceptions at cutouts, terminations,
    and unsupported stations.
    Update the manifest, installation guide, siding notes, and BOM to describe
    the provisional inverted installation, concealed fastening row, revised
    screw quantity, and unresolved production head clearance. Add coverage,
    recessed head envelope, fastening location, and profile orientation cases
    to the US135 tests.
2026-10-25 Clear roof support space for tambour door
    Remove local roof blocks that intrude on the prototype tambour door
    envelope. Roof strips now bear on the existing perimeter framing and
    diagonal, with the clearance documented across the build guides.
    Remove the blocks, routed seats, toe-screw geometry, BOM entries, and
    build-step objects from the model. Update regression expectations and
    roof installation notes to describe the revised bearing arrangement and
    its still-unverified load capacity.
2026-10-25 Route outlet and light branches with UF-B
    Replace the separate light and outlet conduit runs with continuous
    14/2 and 12/2 UF-B cables. Model three watertight connectors at the
    junction box and outlet, remove the round light transition box, and
    update cable routing, junction box fill, BOM, build steps, and
    fabrication guidance for the revised layout.
2026-10-25 Keep backing visible when siding is hidden
    Let the siding toggle hide finish boards and trim while preserving
    structural backing, roof plywood, strip anchors, siding screws, and
    pest mesh. Document the behavior and update the generated OpenSCAD
    assertion.
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2026-10-25 Move animal infill to the interior wall face
    Place animal barriers flush with the inside post faces while keeping the
    separate upper numeral backing 1/4 inch behind the exterior framing.
    Update siding guidance, plywood and screw quantities, and coverage for the
    rear tambour handle clearance.
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2026-10-29 Revise roof board fastening layout
    Move roof strip support beneath the recessed low-Y lip and use one
    concealed screw row per board with shorter screws. Update the generated
    installation guidance, BOM, and roof build steps, plus the gusset cover
    sizes and corresponding documentation and tests.
2026-10-29 Trim gusset cover export for field fit
    Apply the measured rear-edge correction to the back-left fabrication
    export, clipping all cover layers while preserving its installed origin
    and inward edge. Keep the nominal enclosure model unchanged and update
    the fabrication documentation and geometry checks.
2026-11-02 Align back-left gusset cover trim to bearing band
    Update the back-left fabrication trim to end at the default layout's
    rear bearing band, shortening the cover by 2.325 mm to 184.675 mm.
    Keep the nominal enclosure cover length and front-right cover unchanged.
    Revise the fabrication documentation and focused tests to describe and
    check the updated edge alignment and exported dimensions.
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2026-11-09 Add rounded US20 slip socket prototype
    Model the rounded ASA elbow and generous L-profile sockets from
    conservative ink-print estimates. Export fit coupons, miter fixtures,
    CAD views and install notes; check insertion, clearance, travel and
    profile containment.
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2026-11-14 Add minimal US20 rear-clip prototype generator
    Add a separate measured-profile clip with a narrow cover, open rear
    faces, diagonal upper hooks, and shallow lower front claws. Preserve the
    existing slip-socket model and enclosure BOM.
    Provide corner and coupon STEP/STL exports, CAD views, an annotated
    section, and a validation manifest. Expose fit and geometry settings
    through CLI options, including running clearance and exterior transition
    radius.
    Document dimensions, print orientation, fit checks, travel limits, and
    prototype constraints. Add geometry checks for collisions, hook placement,
    open-back clearance, coupons, and exports.
